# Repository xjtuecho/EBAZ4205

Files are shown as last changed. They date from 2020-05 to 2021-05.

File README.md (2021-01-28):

# EBAZ4205

This development board was the control card of Ebit E9+ BTC miner. In mainland China, it cost about 5 dollars (<35 CNY) on the secondhand market.

## Resources

- [Telegram group](https://t.me/ebaz4205) general chat, quick Q&A
- [Wiki](https://github.com/xjtuecho/EBAZ4205/wiki) FAQ, tutorials
- [Github discussions](https://github.com/xjtuecho/EBAZ4205/discussions) troubleshooting help, projects, development

## Hardware summary

Hardware:
- [PDF Schematic](/HW/ebaz4205/EBAZ4205-SCH.pdf)
- [Altium Designer design files](/HW/ebaz4205/altium/)
- [KiCad design files](/HW/ebaz4205/kicad/)
- [CPU info](proc/cpuinfo)

On-board linux
- [Kernel cmdline](proc/cmdline)
- [NAND Memory Map](proc/mtd)
- [Linux Version](proc/version)

The TF card socket is absent by default, you can buy and solder it by yourself if necessary. So do the UART port `J7`and the JTAG port `J8`.
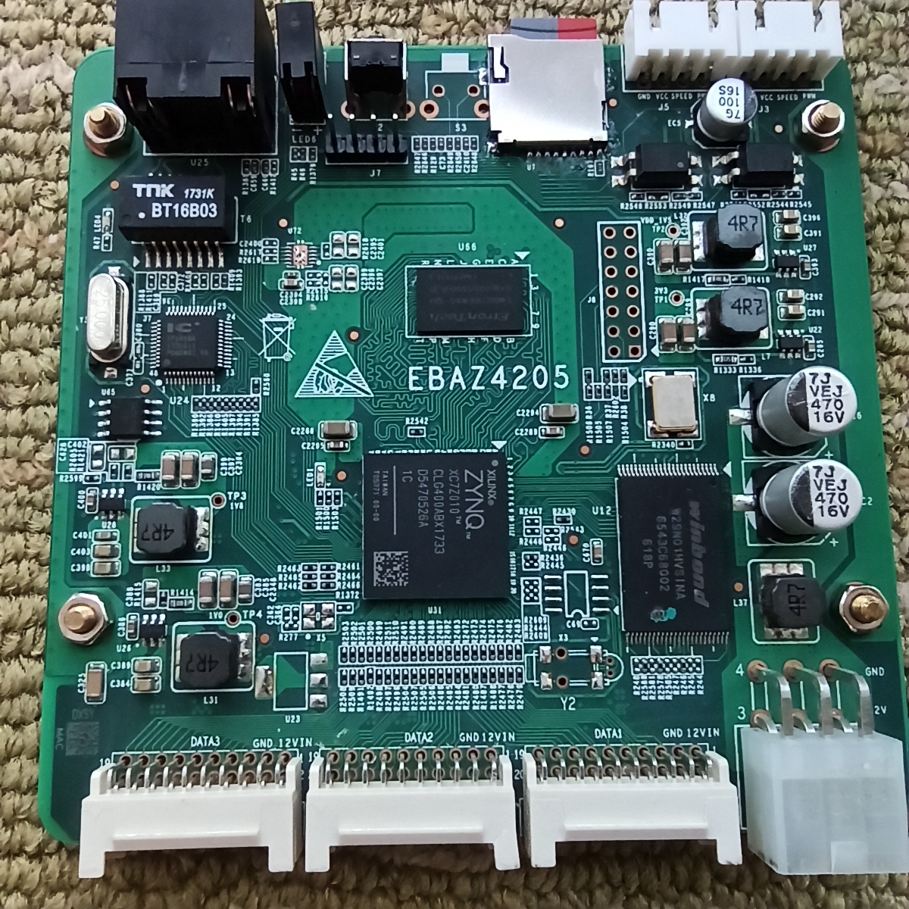
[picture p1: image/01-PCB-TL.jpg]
Top layer of the board


On the bottom layer of the board, diode `D24` is absent by default, which you need if you want to power the board via `J3 J4 J5`. Solder a SMC schottky diode there.
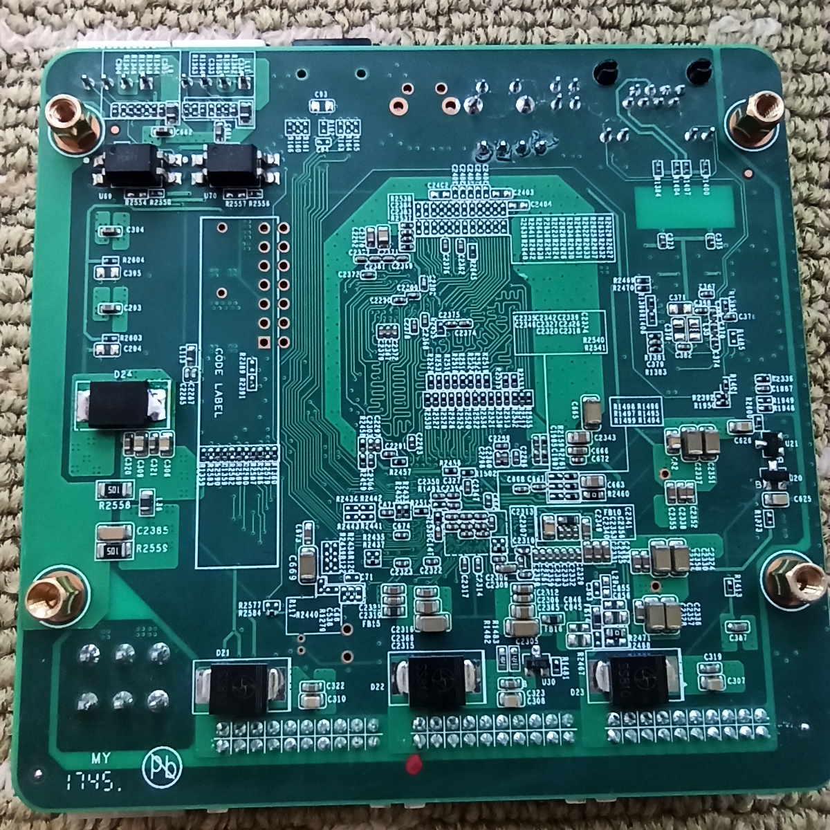
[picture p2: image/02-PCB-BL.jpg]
Bottom layer of the board


XC7Z010CLG400, Dual Core Cortex A9 @ 666.66MHz and Artix-7 FPGA with 28k LEs.
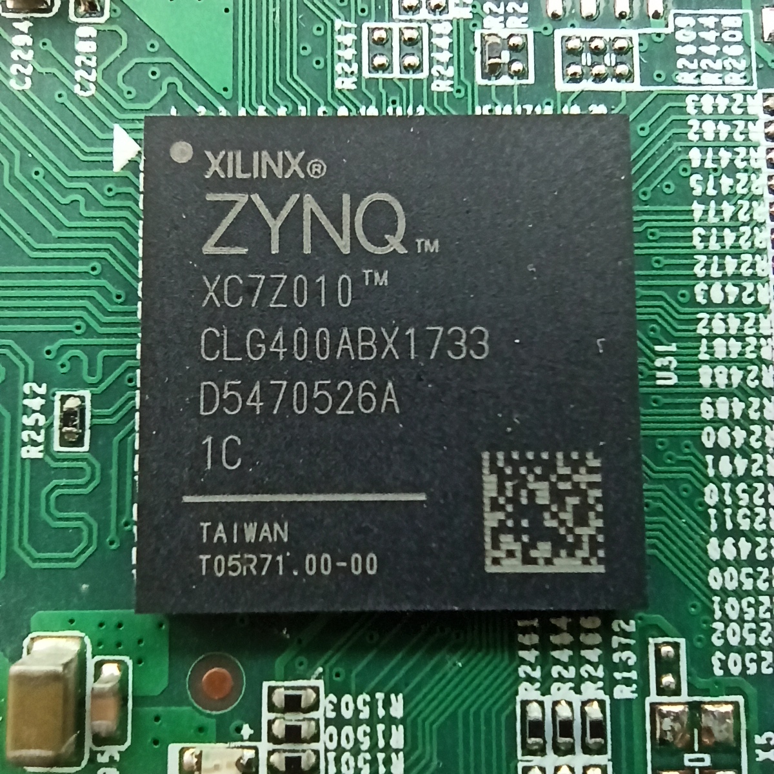
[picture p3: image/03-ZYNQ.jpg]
ZYNQ


256MB DDR3 Dynamic Memory.
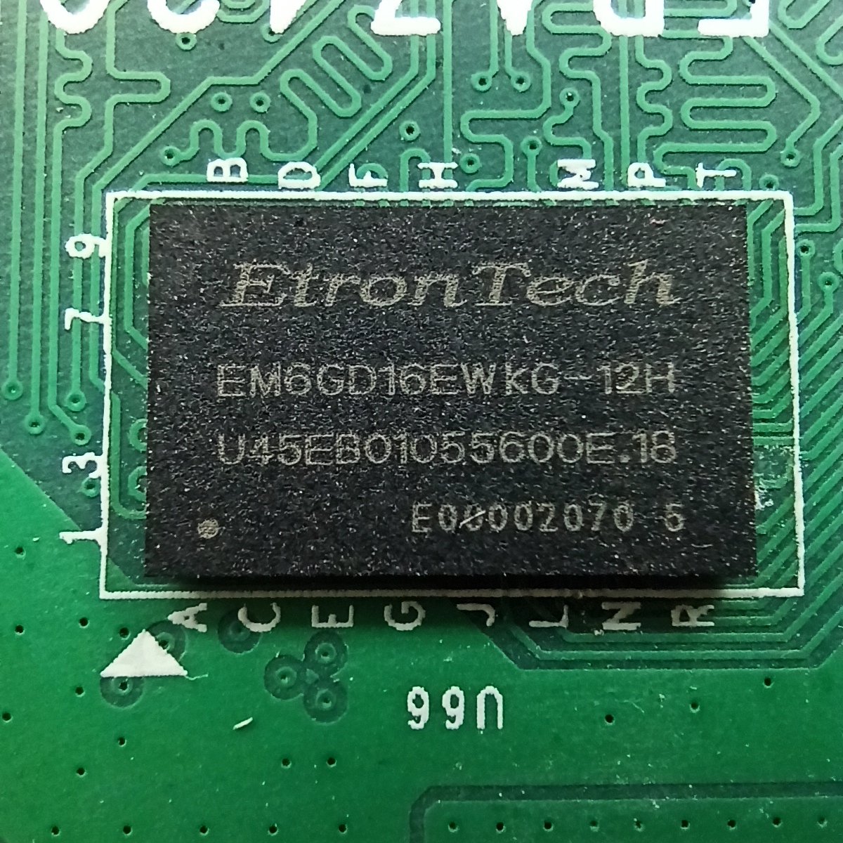
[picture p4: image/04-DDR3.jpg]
DDR3


128MB SLC NAND FLASH.
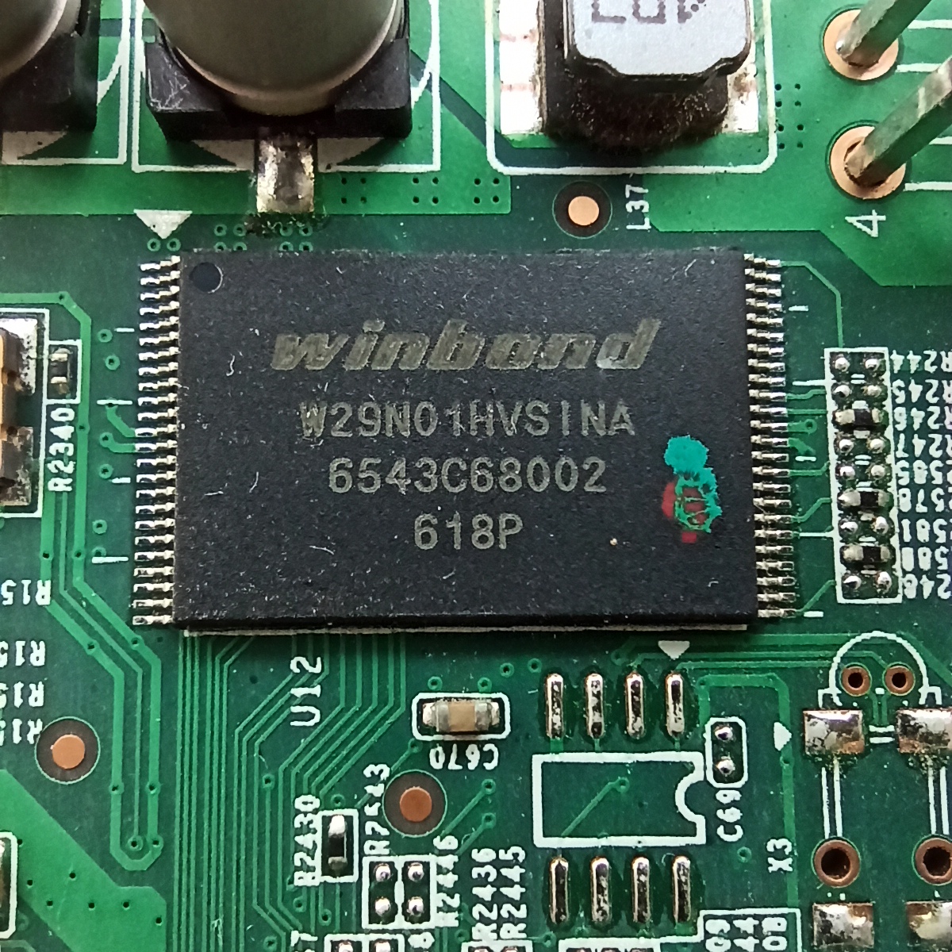
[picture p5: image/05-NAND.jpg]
NAND


10/100Mbps Ethernet transceiver: IP101GA
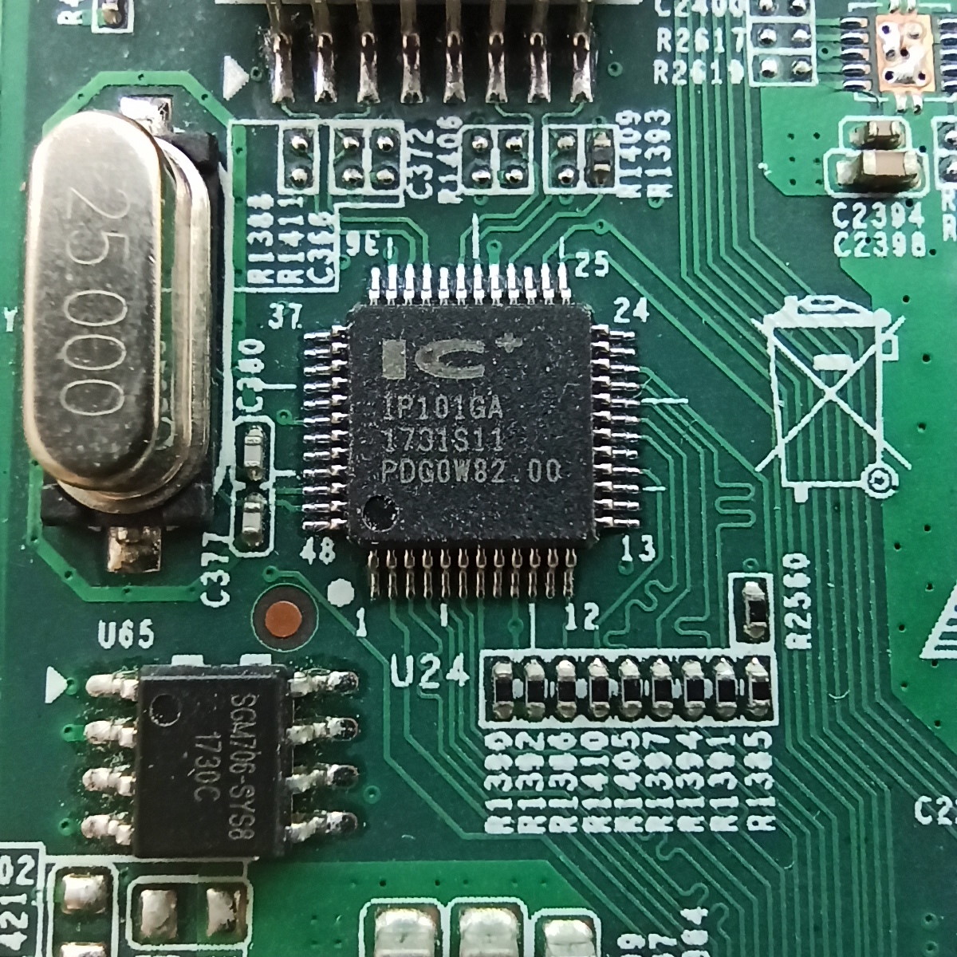
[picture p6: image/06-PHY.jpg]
PHY


BOOT Select Resistor: `R2577 and R2584`. The resistor is on `R2584` by default, which indicates boot from NAND. If you want to boot from TF card, **move** `R2584` to `R2577`.
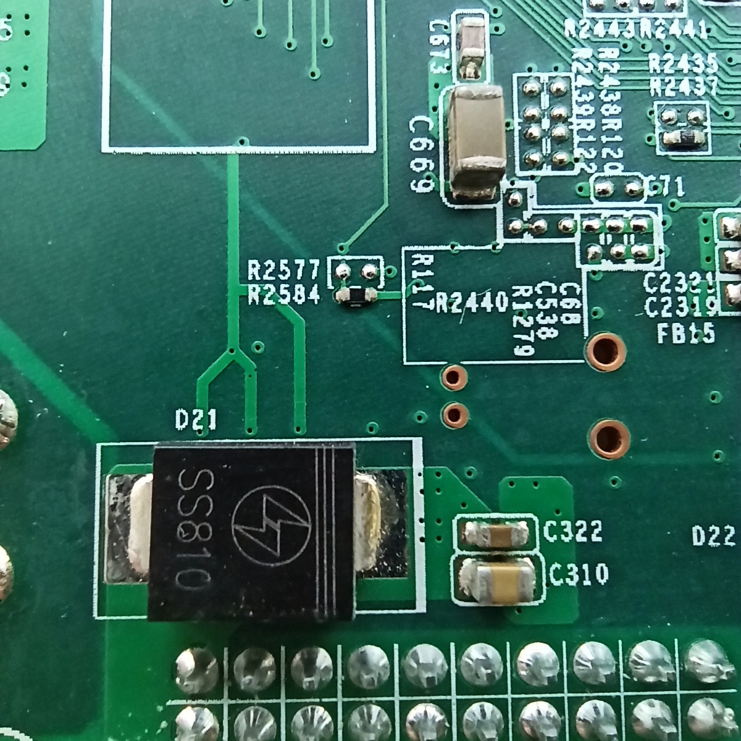
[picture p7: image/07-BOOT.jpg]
BOOT


## Powering the board

If the Schottky Diode `D24` was not mounted, you can only power the board by `DATA1` `DATA2` and `DATA3` port. Voltage 5V~12V is OK, 400mA and above is necessary. The pin distance of these three ports is 2.0mm, which is not common as 2.54mm.

After `D24` was mounted, we can power the board by J3 J4 J5. For convenience, J3 or J5 is recommended, which was originally for FAN power.

## Reset the root password of built-in linux

Use HyperTerminal or Putty to connect the TTL port, TXD RXD and GND is enough, VCC is not necessary. Power the Board, Hit `d` to enter the u-boot shell.

```
setenv nandboot "echo Copying Linux from NAND flash to RAM... && nand info && run nandroot;nand read 0x100000 0x2220000 0x300000 && fpga loadb 0 0x100000 0x300000 && nand read ${kernel_load_address} 0x300000 ${kernel_size} && nand read ${devicetree_load_address} 0x800000 ${devicetree_size}"
run nandboot
setenv bootargs 'console=ttyPS0,115200 root=/dev/mtdblock6 rootfstype=jffs2 noinitrd rw rootwait reboot=cold,hard emergency init=/bin/sh'
bootm ${kernel_load_address} - ${devicetree_load_address} init=/bin/sh
passwd
```

Use the commands above to reset the root password.

## Shut down the BTC miner program

After logging on with root, execute commands below to disable the BTC miner program.

```
mv /etc/rcS.d/S95cgminer.sh /etc/rcS.d/K95cgminer.sh
reboot
```

## Set static IP address

Edit configuration file: `/etc/network/interfaces`, add contents below.

```
auto eth0
iface eth0 inet static
address 192.168.1.205
netmask 255.255.255.0
gateway 192.168.1.1
dns-nameservers 192.168.1.1
```

Enable ethernet: `ifup eth0`.
Check ethernet status: `ethtool eth0`
Now you can use `ssh root@192.168.1.205` to connect the built-in linux.
Of course, you can use other IP address according to your network configuration.

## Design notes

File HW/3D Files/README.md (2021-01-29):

# EBAZ4205 3D Files

## EBAZ4205_Stand.stl

Uses four 5mm M3 Screws.
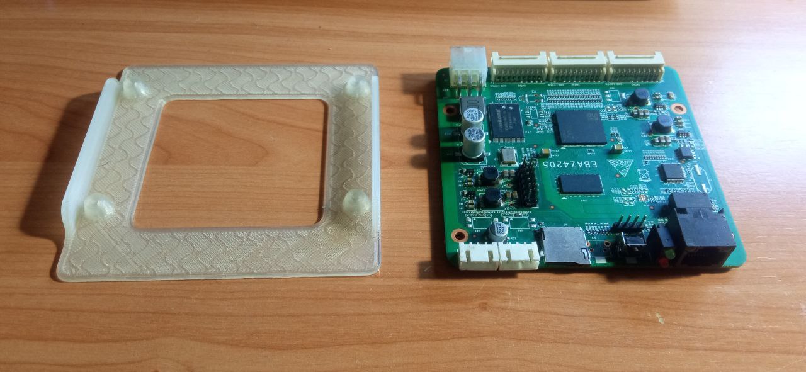
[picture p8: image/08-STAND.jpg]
Unmounted Stand

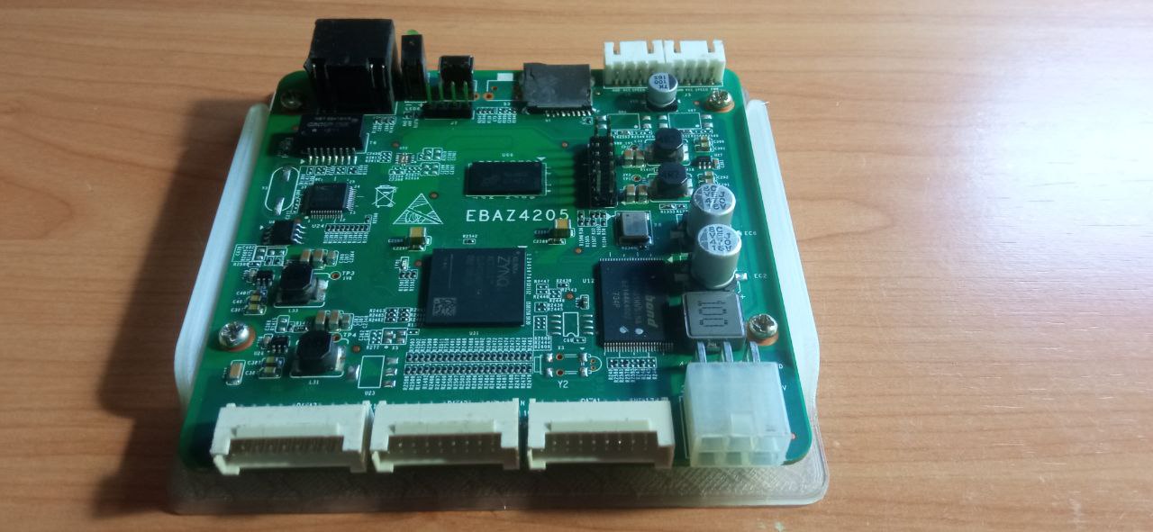
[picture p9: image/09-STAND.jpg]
Mounted Stand


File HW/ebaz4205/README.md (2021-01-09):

# EBAZ4205 PCB designs and schematics

[original](./original) contains the original design (PCB only).

## Altium & KiCad import tutorial

Tools required:
- Altium 20 (21 has importer issues)
- latest KiCad nightly - [Windows builds](https://kicad-downloads.s3.cern.ch/index.html?prefix=windows/nightly/)

1\. Download original PCB file from https://github.com/Elrori/EBAZ4205/blob/master/ebit.pcb

---

2\. Import it in Altium Designer 20 or lower (v21 has a broken importer) via the DXP import wizard

2.1 Use define board shape from bounding rectangle

2.2 Other options are greyed out and turned off

2.3 20mil Internal Plane Pullback (default)

---

3\. Fix import issues in Altium

3.1.1. In PCB List (View > Panels > PCB List) locate "Pads" objects that have "Stack mode property" set to "Top-Middle-Bottom"

3.1.2. In the Properties window, change it to "Simple", keep the Shape "Rectangular"
	   (It will cause DRC issues with polygon fills which we will fix)

3.2. Polygon pour priorities seem to be screwed up and that affects KiCad (since Kicad doesn't keep around filled polygons). \
     It's possible that this is actually an issue of the original design - they poured polygons in parts, never fully.
	 \
     So even though Altium keeps previous fills, we need to to fix that in Altium (has better tools for this) so that it works in KiCad.

3.2.1. Go to Tools > Polygon Pours > Polygon Manager

3.2.2. Select all polygons (Ctrl+A) in Properties set "Hatched" to "Solid", disable "Remove Islands", keep other settings as-is

3.2.3. For every layer, Auto Generate Pour Order

3.2.4. Apply and close Polygon Manager

3.3. Default design rules mangle poly fills

3.3.1. Go to Design > Rules

3.3.2. Set "PolyonConnect" rule "Connect Style" property to "Direct Connect" \
       (This removes thermals reliefs on specific pins, but at least you don't need to dick with DRC rules too much)
	   
3.3.3. Set "Clearance_1" minimum clearance 3.2mil to pass the DRC check \
       (Or, alternatively, fix these issues, there's only 4 or so violations)

3.4. Repour all polygons via Tools > Polygon Pours > Repour All

---

4\. Save the design as ebit_ad.PcbDoc , use "PCB Binary Files" type (this is version 6 of the format, which is expected by the Kicad importer).

---

5\. Import the design in KiCad nightly (I've used 5.99.0-8236-gc3d46c1cb5, Jan 7 2021 22:02:27, CERN Windows build) 

5.1. Open pcbnew directly

5.2. File > Import > Non-KiCad board file, select ebit_ad.PcbDoc (it needs to have the PcbDoc extension!)

5.3. Fix import issues in KiCad \
     Constraints aren't migrated properly (though the values in Altium don't make much sense either) \
	 so we need to manually set it to Altium rules to get comparable results
	 
5.3.1. Go to File > Board Setup

5.3.2. Board Stackup > Physical Stackup, set Board thickness to Current thickness from stackup \
       (or actually fix / adapt it to your manufacturers capabilities)

5.3.3. Design Rules > Constraints, set to Altium rules (or manufacturer capabilities)

  - Copper > Minimum track width to 1 mils
  - Copper > Minimum annular width to 3 mils
  - Copper > Minimum via diameter to 2 mils
  - Copper > Copper edge clearance to 3.2 mils
  - Holes > Minimum through hole to 2 mils
  - Holes > Hole to hole clearance to 10 mils
  - you can ignore other settings

5.3.4. Design Rules > Violation Severity

  - set Miscellaneous > Silkscreen overlap to Ignore
  - set Miscellaneous > Silkscreen clipped by solder mask to Ignore

5.3.5. Project > Net Classes, Default+All nets, set to Altium rules (or manufacturer capabilities)

  - Clearance to 3.2 mils
  - Track Width to 10 mils
  - Via Size to 50 mils
  - Via Drill to 28 mils
  - you can ignore other settings

5.3.6. Apply and close Board Setup

5.4. Set up zone fills

5.4.1. Open Copper Zone Properties (Ctrl+Shift+Z)

5.4.2. Set Electrical Properties

  - Clearance to 3.2 mils
  - Minimum width to 3.2 mils
  - Pad connections to Solid
  - you can ignore other settings

5.4.3. Invoke "Export Settings to Other Zones" and close the Copper Zone Properties

---

6\. Due to https://gitlab.com/kicad/code/kicad/-/issues/5794 (still applicable),
   invoke zone refill in DRC checker to apply new net clearances
   \
   If you set everything as described, the DRC checker shouldn't report any errors
   and all nets should be connected.

---

7\. Save the KiCad design if you haven't already ;)

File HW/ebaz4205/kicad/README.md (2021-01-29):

# Please note

At the time of writing (Jan, 2021) you require a nightly build of KiCad to be able to view this PCB / schematic.

Once KiCad v6 lands, you will be able to use stable versions.

Nightly version was required because the significantly improved Altium PCB importer (bundled within pcbnew, not a standalone tool)
isn't available in the stable builds yet.

KiCad schematic capture (eeschema) has also switched to a new file format (s-expr),
for which it was significantly easier to write a schematic generation tool (https://github.com/tpecar/nl2sch).

## Getting KiCad nightly

If you're on Windows, CERN provides pre-built binaries (see bottom of page for latest version)

https://kicad-downloads.s3.cern.ch/index.html?prefix=windows/nightly/

For Linux it depends on the distribution - for Ubuntu/Debian, the instructions are provided on the KiCad page

https://kicad.org/download/ubuntu/#_nightly_development_builds

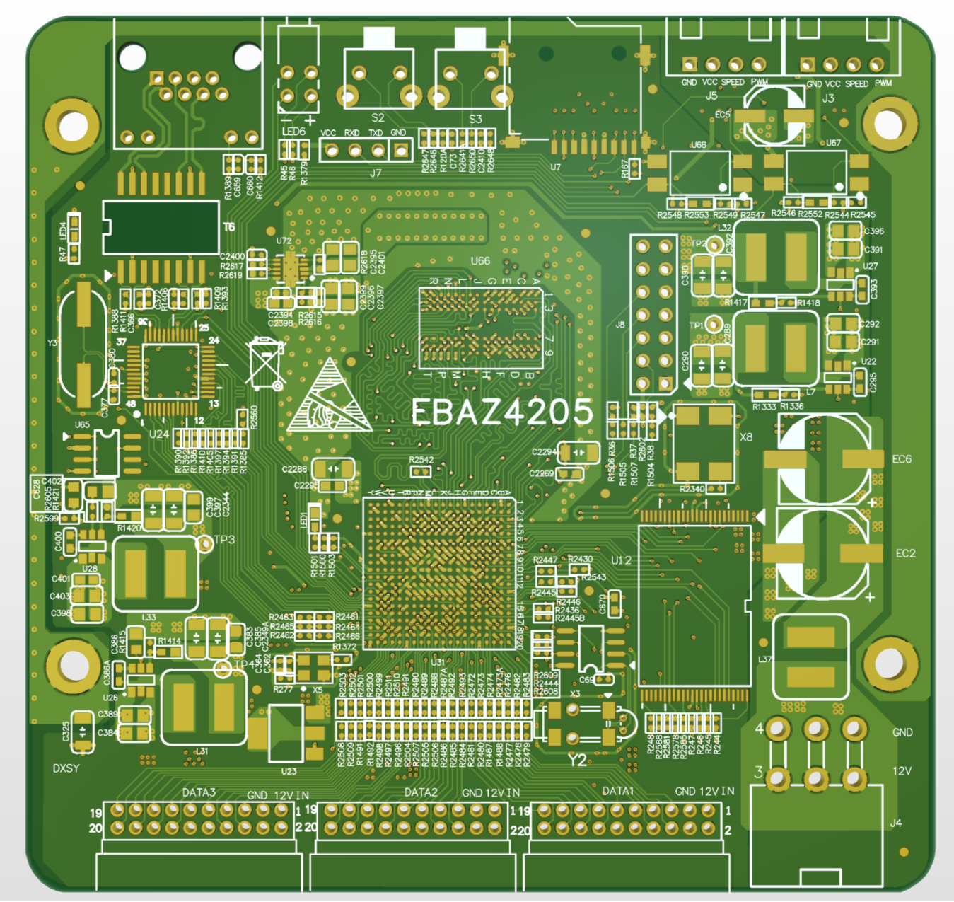
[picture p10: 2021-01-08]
HW/ebaz4205/EBAZ4205-3D.png

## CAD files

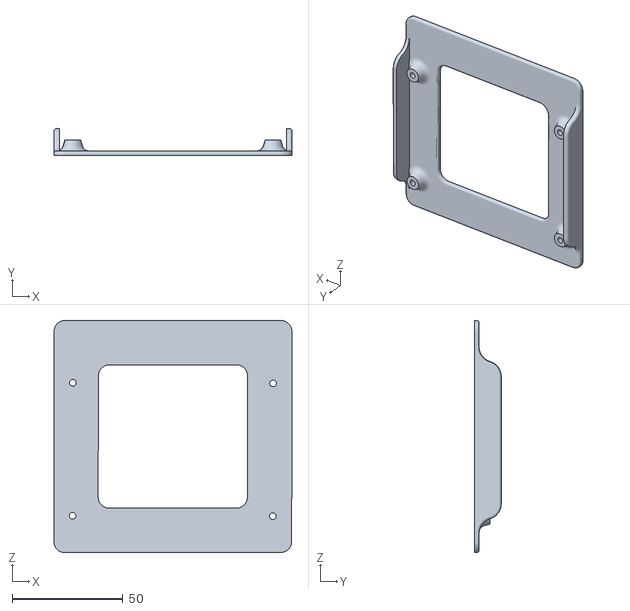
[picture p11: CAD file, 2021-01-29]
HW/3D Files/EBAZ4205_Stand.stl
107.2 x 12.0 x 104.6

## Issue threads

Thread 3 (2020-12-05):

KG4205 Development board VGA &UART

firepower9966, 2020-12-05:
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

Do you have any info on KG4205 Which match the EBAZ4205.  It provides VGA and UART and a 2.54mm  I/O connector which can attach optional camera.

xjtuecho, 2020-12-09:
This KG4205 is an extended card of EBAZ4205. I didn't know more about it, but  I can purchase it easily in my country.

ryanm101, 2020-12-20:
Seems you can buy a few adaptors: https://www.aliexpress.com/item/1005001530233006.html?spm=2114.12057483.0.0.61c9febeBUtvsg

Where can you buy the KG4205 from?

firepower9966, 2020-12-20:
US $17.69  9%OFF | ZYNQ7010 Development Board, Xc7z010 FPGA.
https://a.aliexpress.com/_msejyAv

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

artemglukhov, 2021-02-01:
May I ask you if you know the part number of these 2x10 20mm connectors?

firepower9966, 2021-02-01:
Search for
20 Position 2 mm 2 Row Headers & Wire Housings
Depends if you want wired connector or PCB mount.

BrainHunter, 2021-03-20:
does anyone have schematics for this board?

nic3-14159, 2021-03-20:
> does anyone have schematics for this board?

There's some info about this board in the discussions
https://github.com/xjtuecho/EBAZ4205/discussions/46

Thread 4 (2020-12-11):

Information on readme how to upload bitstream to FPGA?

Kazhuu, 2020-12-11:
Hello! I'm relative new to Xilinx FPGAs and ordered one of these boards. I'm wondering what is the best way to actually do some FPGA development on this board? I think I can put the bitstream file to SD card and let linux upload it to FPGA on boot but cannot find any information about this. Also someone on Reddit mentioned that you need JTAG FPGA programming cable from Xilinx. I guess this would be the best way to do the development? But the cable itself cost something like 80€ I think.

I've used Altera's development boards earlier which can be used with USB cable instead. Thank you!

xjtuecho, 2020-12-11:
Maybe you need a Digilent JTAG-SMT2，the FT232HL_v20.5.31.pdf in this repo is enough. cost about 8$

Kazhuu, 2020-12-11:
Thanks! With this information I was actually able to do some research and found web page describing [programming solutions](https://store.digilentinc.com/jtag-programmers-fpga-programming-solutions/). I'll also had a look at FT232HL board you mentioned and was thinking could [this](https://www.adafruit.com/product/2264) Adafruit one serve similar purpose? Of course with this you have to connect the pins individually.

tpecar, 2020-12-12:
Hi, [I'm probably from the same bandwagon as @Kazhuu](https://hackaday.com/2020/12/10/a-xilinx-zynq-linux-fpga-board-for-under-20-the-windfall-of-decommissioned-crypto-mining/).

With a bunch of these on the way I'm also in the process of figuring out how to use them :rofl:

The cheapest way to get going is probably to just build the SD card image and boot the board from that. Most examples available for this board go this way
- https://www.jianshu.com/p/b83c663ecaaa
- https://gitee.com/actionchen/ebaz4205_hw/blob/master/Doc/ebaz4205_introduce.md
- https://www.youtube.com/watch?v=b6g5tNZZnVc

However, in order to debug a baremetal application running on PS (ARM core) and to not loose sanity swapping SD cards, I also want to figure out how to use JTAG.

#### The easy and expensive way of doing this
The [Digitlent JTAG cables](https://store.digilentinc.com/jtag-programmers-fpga-programming-solutions/) are the official cables that are supported by Xilinx tools. If you want the minimum amount of fuss, get one of these.

However, given that they are only glorified FTDI dongles programmed with configuration blessed by Xilinx, it makes me a bit mad spending $60 for one of these.

#### The cheap and finnicky way of doing this
While I couldn't find a product that uses the exact design specified in FT232HL_v20.5.31.pdf, I suppose that most generic FTDI JTAG dongles are applicable here.

You can then use [OpenOCD](http://openocd.org/) or [xc3sprog](http://xc3sprog.sourceforge.net/) to download the bitstream to the fpga (provided that you have boot mode pins set to JTAG - these are the same pins @xjtuecho suggests to change to get SDcard boot).

There's a couple of gotchas however:
- xc3sprog is only capable of setting up the PL (FPGA) side, PS (ARM core) is uninitialized
- OpenOCD has support to set up PL / PS sections
  - [OpenOCD page](https://devel.rtems.org/wiki/Debugging/OpenOCD/Xilinx_Zynq) has configuration files for Zynq but it needs to be adapted to your specific chip
  - [Zynq-RS project](https://git.m-labs.hk/M-Labs/zynq-rs) has configuration files set up for Z7-10

  but is not supported by Xilinx, so there's probably some effort required to get a decent debugging environment
- none of these metods give you access to [ILA](https://www.xilinx.com/video/hardware/logic-debug-in-vivado.html)

Then you have _Xilinx Virtual Cable (XVC)_.
Seems to be the most interesting method. Instead of talking to the debug probe directly, the Xilinx tools talk to a XVC deamon over TCP/IP, which can run on your system or some other device, which is actually connected to your target
- [original XVC deamon](https://debugmo.de/2012/02/xvcd-the-xilinx-virtual-cable-daemon/) and [its sister project](https://code.google.com/archive/p/playtag/) run on your development system and talk to the target via FTDI2232 (essentially bypassing the silly restrictions). However, these projects seem to be inactive.
- [Xilinx has reworked this code to run directly on a Zynq platform](https://github.com/Xilinx/XilinxVirtualCable), so if you have more than one board, you can use one as a debug probe.
- [somebody has ported the Xilinx example on the Raspberry Pi](https://github.com/derekmulcahy/xvcpi) so you can try that.

Kazhuu, 2020-12-12:
@tpecar thanks for the very detailed answer! This really helps people like me to get started and learning. Very appreciated! I think I might end up buying a cable from Digilent because it can also be used in the future with different boards. And I'm interested in the debugging support which is quite mandatory when doing anything more complicated.

One thing I'm wondering. If I buy JTAG-HS3 instead of JTAG-HS2. HS3 has support for PS_SRST pin resetting the processor during debugging. Although I checked the schematics of this board and it seems this pin is not connected to JTAG header. I'm guessing if you want PS_SRST pin support then you'd need to modify the board.  Here is good explanation of [PS_SRST](https://forum.digilentinc.com/topic/580-jtag-hs3-vs-jtag-hs2-when-using-zynq-with-vivado/).

tpecar, 2020-12-12:
Well, given that they sell both JTAG-HS2 and JTAG-HS3 for the same price, I guess you select the one that better fits your use case.

HS2 supports [2-Wire JTAG](https://sudonull.com/post/106128-We-disassemble-the-2-wire-JTAG-protocol), but since we already have standard JTAG routed out, this is a non-issue.

HS3, as you mentioned, has an open drain output which the Xilinx tools can use for PS reset.

The PS_SRST_B (B10 on CLG400 package) is routed out to R2430 (pullup to VCC) which is perfect - just run a bodge wire to the JTAG connector (pin 12, 14 of the connector seem to be disconnected).

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

Kazhuu, 2020-12-13:
Thanks you for you detailed answer! I'll order one and try it out. Sorry might be beginner question but what I understood that HS3 has open drain outputs, meaning that I have to connect it to VCC pull up like you said. So in this case I need to connect from the **left side** of the resistor to pin 14 like so.

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

tpecar, 2020-12-13:
Yep, that should work.

It obviously needs to be tested, and I probably have a good 2 months before I get the boards, so if you can try that earlier I'll appreciate your report.

Once it gets tested, we can consider integrating it into the readme.

Kazhuu, 2020-12-13:
Sounds good. I can test it but it might not be very soon because I'm not at home during Christmas holidays and getting that cable to Finland will take some time delivered. I'll report here when I've tested this.

tpecar, 2020-12-13:
> getting that cable to Finland will take some time delivered

Just in case you didn't notice, Digilent has European distributors - you can get the cable at [Farnell for example](https://analytics.oemsecrets.com/main.php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).

ustcpetergu, 2020-12-16:
Actually, you can download the bitstream over ethernet in u-boot. So no need to solder SD card slot or buy expensive JTAG downloaders. UART is still needed though.

Set up a tftp server on host computer and in u-boot use command similar to this:
```
<press d>
setenv serverip 192.168.6.6
setenv ipaddr 192.168.6.136
tftpboot 0x100000 bd_hello_wrapper.bit.bin
fpga load 0 0x100000 0x1fcba0

reset
```
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
xjtuecho, 2021-01-28:
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
What's the version of you KiCad? I can't open the KiCad project with latest KiCad 5.1.9-1

tpecar, 2021-01-28:
I'm using nightly build of kicad (compiled from current git master), it's numbered as version 5.99.

I've needed to use nightly because the have significantly improved the Altium PCB importer and they have switched to s-expr file format for eeschema, for which it was easier to write a schematic generation tool.

If you're on Windows, CERN provides prebuilt binaries (see bottom of page for latest version)
https://kicad-downloads.s3.cern.ch/index.html?prefix=windows/nightly/

For linux it depends on the distribution - for Ubuntu/Debian, the instructions are provided on the Kicad page
https://kicad.org/download/ubuntu/#_nightly_development_builds

M3m3M4n, 2021-09-27:
> And about JTAG downloader, I did by one later. But of course not the expensive official one. I just picked a CJMCU FT232HL(the one with purple PCB, which is quite common) module and flashed the EEPROM. Similar to this: https://gist.github.com/rikka0w0/24b58b54473227502fa0334bbe75c3c1
>
> The firmware between FT232 and FT2232 may be a little different so the gist may not work out-of-the-box, but I got it working at last. Only cost me 30RMB.

@regymm Does the firmware need to be modified? can you share the binary?

regymm, 2021-09-27:
For FT2232 just follow the link. You can try this one(use xxd to reverse to binary) for FT232, and change the product_id and file name in the link-provided configuration file accordingly. Run `dmesg --follow` and re-plug your downloader to see whether the firmware is successfully flashed. May need multiple tries but this is not that hard.
```
00000000: 0100 0304 1460 0009 8000 0800 0000 a012  .....`..........
00000010: b228 da1a 0000 0000 0000 0000 0000 5600  .(............V.
00000020: 0100 c792 6a35 5401 0031 4a74 6167 536d  ....j5T..1JtagSm
00000030: 7432 0000 0000 0000 0000 0044 6967 696c  t2.........Digil
00000040: 656e 7420 4a54 4147 2d53 4d54 3200 0000  ent JTAG-SMT2...
00000050: 0000 0000 0000 0000 1300 0000 0000 0000  ................
00000060: 0000 0000 0000 0000 0000 0000 0000 0000  ................
00000070: 0000 0000 0000 0000 0000 0000 0000 0000  ................
00000080: 0000 0000 0000 0000 0000 4800 0000 0000  ..........H.....
00000090: 0000 0000 0000 0000 0000 0000 0000 0000  ................
000000a0: 1203 4400 6900 6700 6900 6c00 6500 6e00  ..D.i.g.i.l.e.n.
000000b0: 7400 2803 4400 6900 6700 6900 6c00 6500  t.(.D.i.g.i.l.e.
000000c0: 6e00 7400 2000 5500 5300 4200 2000 4400  n.t. .U.S.B. .D.
000000d0: 6500 7600 6900 6300 6500 1a03 3200 3100  e.v.i.c.e...2.1.
000000e0: 3000 3200 3500 3100 4100 3000 3800 3800  0.2.5.1.A.0.8.8.
000000f0: 3700 3000 0203 0000 0000 0000 0000 9887  7.0.............
```

M3m3M4n, 2021-09-27:
Thanks.
Also earlier I missed a comment on https://gist.github.com/rikka0w0/24b58b54473227502fa0334bbe75c3c1 that mentions the HS2 firmware is confirmed working with 232h.

AndersBNielsen, 2021-12-10:
I have a FT232 coming in the mail but to anyone that has a Raspberry Pi around: xvcpi was suuuuper easy to use.
Simply connect it to the "SPI" port on the RPi + GPIO25 and you can connect through Vivado. Super handy with a Pi Zero W - Wireless JTAG :)

regymm, 2021-12-10:
Yeah, RPi's neat. How long does it take to program ZYNQ 7010? I'd like to use RPi but seems on my side it takes more than half a minute and when using ILA to capture data it's very slow.

nic3-14159, 2021-12-12:
@regymm  The xvcpi code, built without changes, programs my board in about 20s. Lowering the clock delay as much as I could, I was able to get it down to about 8s. However, there seems to be a timing issue with the code which limits the minimum clock delay/maximum clock rate, after fixing that (I have a pull request open in the original repo) I was able to get the programming speed down to 3s after setting the clock delay to 0.

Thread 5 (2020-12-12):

SchDoc for EBAZ4205.PcbDoc

tpecar, 2020-12-12:
Do you have access to the PcbSch (schematic file) of the design?

We can obviously make do with the pdf export, but the actual design file would be welcome so that we can utilize cross-probing in Altium.

tpecar, 2020-12-12:
Also, correct me if I'm wrong, but it seems that some traces / planes are missing in the PCB design?

Notably, some VCC lines (I've looked at R2430) don't seem to go anywhere.

xjtuecho, 2020-12-13:
sorry, no .schdoc. The pdf schematic and PcbDoc are probably not the original design. Maybe they are the product of some reverse engeering.

tpecar, 2020-12-13:
Ok, thank you. The design files probably originate from the initial design, but it seems that someone has removed a couple of nets while this design was passed around.

It seems that the original reseller of this board on AliExpress was aware of such versions, noting "PCB (ad format copy board diagram, you can only refer to it, it is not recommended to proof)".

In the meantime I've found a more complete PcbDoc at
https://github.com/Elrori/EBAZ4205

I'll contact him to see if he has any more info.

tpecar, 2020-12-19:
Well, I'm currently still waiting for an answer from Elrori, but I did some digging of my own in the meantime.

This board was making rounds on chinese EE forums in the early/mid 2019, and the relevant development resources have been reposted many times over. We're probably well past the point where anyone affected would care about further distributing these files, so the least we can do is organize them.

@xjtuecho I suggest that you have a look at Elrori's version of the pcbdoc and replace your version with his.

tpecar, 2020-12-19:
Here's a couple forum threads from when the boards initially hit the chinese flea market.
I didn't yet bother to register on them, so I didn't check the files.

- http://bbs.eeworld.com.cn/thread-1078942-1-1.html
- http://bbs.eeworld.com.cn/thread-1079275-1-1.html
- https://whycan.com/t_2297.html
- https://www.amobbs.com/thread-5708955-1-1.html#postmessage_10672027

Also http://dengkanwen.com/ seems to run http://www.opensoc.cn/ which sells expansion boards that were mentioned in some other issue, but most of their documentation seems broken.

tpecar, 2021-01-05:
After looking around various forums and looking through the materials that people have gathered on the Telegram group, we can assume that the original schematic file was never shared.

So if we want cross probing, we'll have to recreate it.

I will close this issue when I transfer the useful information to the Wiki.

Closed 2021-01-05.

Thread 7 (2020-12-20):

Frequency info

doppioandante, 2020-12-20:
If I can correctly interpret the pics, the external crystal is at 25MHz, is this correct? Does the FPGA run at this frequency?

tpecar, 2020-12-20:
The 25MHz crystal (Y3) is for the ethernet phy.

Zynq uses the 33.333MHz crystal (X8), which can then be internally multiplied by a PLL - this depends on your design, the firmware already present on the flash chip seems to use 666.66 MHz for the ARM core (judging from the BogoMIPS).

The overview datasheet specifies max frequency 667MHz for grade 1 Z-7010  used on these boards. But again, the actual frequency you can use will be determined by your design.

doppioandante, 2020-12-20:
Thank you, that's exactly what I needed to know

Closed 2020-12-20.

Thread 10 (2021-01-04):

Add categories to Github discussions

tpecar, 2021-01-04:
Add additional categories which would be useful to the project

- Troubleshooting - for helping people setting up their board
- Documentation - for discussion about tutorials, learning materials, Wiki
- Development - for research on the development board, promotion of useful tools and projects

I would use the "Open ended discussion" format for these.

Existing categories are very general, but I would keep them for whatever discussion that doesn't fit in the suggested categories.

tpecar, 2021-01-05:
Thank you for creating the categories.

Closed 2021-01-05.

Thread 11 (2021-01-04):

Get schematics etc from behind the great wechat paywall

ryanm101, 2021-01-04:
This issue is to track a list of files we want to gather that have been uploaded to various sites that require wechat accounts to download from.

Closed 2021-01-04.

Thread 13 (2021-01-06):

Missing Components

firepower9966, 2021-01-06:
I just received my EBAZ4205 from aliexpress, I noticed some components are missing compared to PCB in Photo
Missing: (next to J5, J3)
U67, R2546, R2544, R2545
U68, R2548, R2549, R2547
U69, R2554, R2551
U70, R2557, R2555
Added:
R2553, R2552, R2554, R2557

Missing: (Lan)
Y3 25MHz xtal
C377, C380 22pF

tpecar, 2021-01-06:
There are at least two known hardware revisions of the board:
1. version, pictured in the repo README, which has the phy + optocouplers
2. version (**what you have**), where these components (+various resistors and caps) are missing

They presumably use the same PCB. It has been speculated that they have different software / bitstream configurations and that in the 2nd version the FPGA generates the clock for the phy.

However, I haven't looked into this myself, other members may have more information on this.

Kudos for identifying the missing components and measuring their values - I suggest that you add them to [hardware build states wiki page](https://github.com/xjtuecho/EBAZ4205/wiki/Hardware-Build-States.-What-you-may-or-not-have-fitted-on-your-board.).

tpecar, 2021-01-06:
Also, it's probably a good idea that people start nagging their sellers to partially refund them for falsely advertising their product and to force them to update the product image.

Most, if not all, sellers use the 1. version for the product image (which was probably made early in the devices product cycle) but sell you the 2nd. There have been numerous reports about this already.

firepower9966, 2021-01-06:
my seller sold both types, i selected the cheaper version which had no sdcard and jumpers, but they were supplied to be soldered by user. did not realized other components were missing though, pictures of both boards were shown.

nic3-14159, 2021-01-06:
Mine was missing the opto-isolators and 25MHz crystal as well, where the opto-isolators were bypassed by those extra 33 ohm resistors. I took a look at the schematic and my board and found that the 10k ohm resistors R1344 and R1361 are pull-ups to 3.3V on pin 3 (labeled as SPEED on the board) of both J3 and J5. So using logic levels of less than 3.3V on those pins should probably be avoided if using a board with the missing components. Alternatively, just remove those resistors.

Looking at the schematic again, it seems like if the opto-isolators are present, R2350 (the board seems to say R2550, but the schematic says R2350) and R2556 pull up pin 4 on J3/J5 to VCC8, which is whatever voltage is on J4 or pin 2 on J3/J5. Those resistors are missing on the 2nd version of the board. With the opto-isolator, pin 4 (labled as PWM on the board) can only be used as an output, and the pull-up resistors means that the logical high voltage will be whatever VCC8 is. So if you have added the D24 diode to use J3/4/5 as the main power source, make sure that whatever is connected to pin 4 pin J3/5 can handle that voltage if using a board with the isolators.

I'll add this info to the wiki.

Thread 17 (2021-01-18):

Error running bootm command

dave18, 2021-01-18:
Hi

When trying to reset the password I get the following error when running the bootm command 'waiting for root device /dev/mtdblock6', the full Putty log is

------------------------------------------------------------
`
U-Boot 2015.07 (May 18 2017 - 22:22:09 +0800)

Model: Zynq Zed Development Board
DRAM:  ECC disabled 256 MiB
NAND:  128 MiB
MMC:   zynq_sdhci: 0
Invalid bus 0 (err=-1)
*** Warning - spi_flash_probe() failed, using default environment

In:    serial
Out:   serial
Err:   serial
Model: Zynq Zed Development Board
Net:   Gem.e000b000
Hit 'd' to stop autoboot(eric): 0
zynq-uboot> setenv nandboot "echo Copying Linux from NAND flash to RAM... && nand info && run nandroot;nand read 0x100000 0x2220000 0x300000 && fpga loadb 0 0x100000 0x300000 && nand read ${kernel_load_address} 0x300000 ${kernel_size} && nand read ${devicetree_load_address} 0x800000 ${devicetree_size}"
zynq-uboot> run nandboot
Copying Linux from NAND flash to RAM...

Device 0: nand0, sector size 128 KiB
  Page size       2048 b
  OOB size          64 b
  Erase size    131072 b
  subpagesize      512 b
  options     0x       0
  bbt options 0x   20000
## Error: "nandroot" not defined

NAND read: device 0 offset 0x2220000, size 0x300000
 3145728 bytes read: OK
  design filename = "top_ctrl;UserID=0XFFFFFFFF;Version=2016.4"
  part number = "7z010clg400"
  date = "2017/05/29"
  time = "11:17:01"
  bytes in bitstream = 2083740
zynq_align_dma_buffer: Align buffer at 100068 to 100000(swap 1)

NAND read: device 0 offset 0x300000, size 0x500000
 5242880 bytes read: OK

NAND read: device 0 offset 0x800000, size 0x20000
 131072 bytes read: OK
zynq-uboot> setenv bootargs 'console=ttyPS0,115200 root=/dev/mtdblock6 rootfstype=jffs2 noinitrd rw rootwait reboot=cold,hard emergency init=/bin/sh'
zynq-uboot> bootm ${kernel_load_address} - ${devicetree_load_address} init=/bin/sh
## Booting kernel from Legacy Image at 02080000 ...
   Image Name:   Linux-4.6.0-xilinx
   Image Type:   ARM Linux Kernel Image (uncompressed)
   Data Size:    3820688 Bytes = 3.6 MiB
   Load Address: 00008000
   Entry Point:  00008000
   Verifying Checksum ... OK
## Flattened Device Tree blob at 02000000
   Booting using the fdt blob at 0x2000000
   Loading Kernel Image ... OK
   Loading Device Tree to 0f2fe000, end 0f303a6b ... OK

Starting kernel ...

Booting Linux on physical CPU 0x0
Linux version 4.6.0-xilinx (root@alvin) (gcc version 5.2.0 (GCC) ) #5 SMP PREEMPT Mon May 8 14:36:49 CST 2017
CPU: ARMv7 Processor [413fc090] revision 0 (ARMv7), cr=18c5387d
CPU: PIPT / VIPT nonaliasing data cache, VIPT aliasing instruction cache
Machine model: xlnx,zynq-7000
cma: Reserved 16 MiB at 0x0e000000
Memory policy: Data cache writealloc
percpu: Embedded 12 pages/cpu @cfdcf000 s19776 r8192 d21184 u49152
Built 1 zonelists in Zone order, mobility grouping on.  Total pages: 65024
Kernel command line: console=ttyPS0,115200 root=/dev/mtdblock6 rootfstype=jffs2 noinitrd rw rootwait reboot=cold,hard emergency init=/bin/sh
PID hash table entries: 1024 (order: 0, 4096 bytes)
Dentry cache hash table entries: 32768 (order: 5, 131072 bytes)
Inode-cache hash table entries: 16384 (order: 4, 65536 bytes)
Memory: 234624K/262144K available (5286K kernel code, 231K rwdata, 1848K rodata, 1024K init, 226K bss, 11136K reserved, 16384K cma-reserved, 0K highmem)
Virtual kernel memory layout:
    vector  : 0xffff0000 - 0xffff1000   (   4 kB)
    fixmap  : 0xffc00000 - 0xfff00000   (3072 kB)
    vmalloc : 0xd0800000 - 0xff800000   ( 752 MB)
    lowmem  : 0xc0000000 - 0xd0000000   ( 256 MB)
    pkmap   : 0xbfe00000 - 0xc0000000   (   2 MB)
    modules : 0xbf000000 - 0xbfe00000   (  14 MB)
      .text : 0xc0008000 - 0xc07f7850   (8127 kB)
      .init : 0xc0800000 - 0xc0900000   (1024 kB)
      .data : 0xc0900000 - 0xc0939e60   ( 232 kB)
       .bss : 0xc0939e60 - 0xc0972764   ( 227 kB)
Preemptible hierarchical RCU implementation.
        Build-time adjustment of leaf fanout to 32.
        RCU restricting CPUs from NR_CPUS=4 to nr_cpu_ids=2.
RCU: Adjusting geometry for rcu_fanout_leaf=32, nr_cpu_ids=2
NR_IRQS:16 nr_irqs:16 16
efuse mapped to d0800000
slcr mapped to d0802000
L2C: platform modifies aux control register: 0x72360000 -> 0x72760000
L2C: DT/platform modifies aux control register: 0x72360000 -> 0x72760000
L2C-310 erratum 769419 enabled
L2C-310 enabling early BRESP for Cortex-A9
L2C-310 full line of zeros enabled for Cortex-A9
L2C-310 ID prefetch enabled, offset 1 lines
L2C-310 dynamic clock gating enabled, standby mode enabled
L2C-310 cache controller enabled, 8 ways, 512 kB
L2C-310: CACHE_ID 0x410000c8, AUX_CTRL 0x76760001
zynq_clock_init: clkc starts at d0802100
Zynq clock init
sched_clock: 64 bits at 333MHz, resolution 3ns, wraps every 4398046511103ns
clocksource: arm_global_timer: mask: 0xffffffffffffffff max_cycles: 0x4ce076117e, max_idle_ns: 440795215954 ns
Switching to timer-based delay loop, resolution 3ns
clocksource: ttc_clocksource: mask: 0xffff max_cycles: 0xffff, max_idle_ns: 537538477 ns
timer #0 at d080a000, irq=17
Console: colour dummy device 80x30
Calibrating delay loop (skipped), value calculated using timer frequency.. 666.66 BogoMIPS (lpj=3333330)
pid_max: default: 32768 minimum: 301
Mount-cache hash table entries: 1024 (order: 0, 4096 bytes)
Mountpoint-cache hash table entries: 1024 (order: 0, 4096 bytes)
CPU: Testing write buffer coherency: ok
CPU0: thread -1, cpu 0, socket 0, mpidr 80000000
Setting up static identity map for 0x100000 - 0x100058
CPU1: thread -1, cpu 1, socket 0, mpidr 80000001
Brought up 2 CPUs
SMP: Total of 2 processors activated (1333.33 BogoMIPS).
CPU: All CPU(s) started in SVC mode.
devtmpfs: initialized
VFP support v0.3: implementor 41 architecture 3 part 30 variant 9 rev 4
clocksource: jiffies: mask: 0xffffffff max_cycles: 0xffffffff, max_idle_ns: 19112604462750000 ns
pinctrl core: initialized pinctrl subsystem
NET: Registered protocol family 16
DMA: preallocated 256 KiB pool for atomic coherent allocations
cpuidle: using governor menu
hw-breakpoint: found 5 (+1 reserved) breakpoint and 1 watchpoint registers.
hw-breakpoint: maximum watchpoint size is 4 bytes.
zynq-ocm f800c000.ocmc: ZYNQ OCM pool: 256 KiB @ 0xd0880000
zynq-pinctrl 700.pinctrl: zynq pinctrl initialized
vgaarb: loaded
SCSI subsystem initialized
usbcore: registered new interface driver usbfs
usbcore: registered new interface driver hub
usbcore: registered new device driver usb
media: Linux media interface: v0.10
Linux video capture interface: v2.00
pps_core: LinuxPPS API ver. 1 registered
pps_core: Software ver. 5.3.6 - Copyright 2005-2007 Rodolfo Giometti <giometti@linux.it>
PTP clock support registered
EDAC MC: Ver: 3.0.0
Advanced Linux Sound Architecture Driver Initialized.
clocksource: Switched to clocksource arm_global_timer
NET: Registered protocol family 2
TCP established hash table entries: 2048 (order: 1, 8192 bytes)
TCP bind hash table entries: 2048 (order: 2, 16384 bytes)
TCP: Hash tables configured (established 2048 bind 2048)
UDP hash table entries: 256 (order: 1, 8192 bytes)
UDP-Lite hash table entries: 256 (order: 1, 8192 bytes)
NET: Registered protocol family 1
RPC: Registered named UNIX socket transport module.
RPC: Registered udp transport module.
RPC: Registered tcp transport module.
RPC: Registered tcp NFSv4.1 backchannel transport module.
hw perfevents: enabled with armv7_cortex_a9 PMU driver, 7 counters available
futex hash table entries: 512 (order: 3, 32768 bytes)
workingset: timestamp_bits=28 max_order=16 bucket_order=0
jffs2: version 2.2. (NAND) (SUMMARY)  © 2001-2006 Red Hat, Inc.
io scheduler noop registered
io scheduler deadline registered
io scheduler cfq registered (default)
dma-pl330 f8003000.dmac: Loaded driver for PL330 DMAC-241330
dma-pl330 f8003000.dmac:        DBUFF-128x8bytes Num_Chans-8 Num_Peri-4 Num_Events-16
42c00000.serial: ttyUL2 at MMIO 0x42c00000 (irq = 166, base_baud = 0) is a uartlite
e0000000.serial: ttyPS1 at MMIO 0xe0000000 (irq = 144, base_baud = 3124996) is a xuartps
e0001000.serial: ttyPS0 at MMIO 0xe0001000 (irq = 145, base_baud = 3124996) is a xuartps
console [ttyPS0] enabled
xdevcfg f8007000.devcfg: ioremap 0xf8007000 to d0872000
[drm] Initialized drm 1.1.0 20060810
brd: module loaded
loop: module loaded
CAN device driver interface
gpiod_set_value: invalid GPIO
libphy: MACB_mii_bus: probed
macb e000b000.ethernet eth0: Cadence GEM rev 0x00020118 at 0xe000b000 irq 148 (00:0a:35:00:01:22)
ICPlus IP101A/G e000b000.etherne:00: attached PHY driver [ICPlus IP101A/G] (mii_bus:phy_addr=e000b000.etherne:00, irq=-1)
e1000e: Intel(R) PRO/1000 Network Driver - 3.2.6-k
e1000e: Copyright(c) 1999 - 2015 Intel Corporation.
ehci_hcd: USB 2.0 'Enhanced' Host Controller (EHCI) Driver
ehci-pci: EHCI PCI platform driver
usbcore: registered new interface driver usb-storage
mousedev: PS/2 mouse device common for all mice
i2c /dev entries driver
rtc-pcf8563 0-0051: chip found, driver version 0.4.4
rtc-pcf8563 0-0051: pcf8563_write_block_data: err=-11 addr=0e, data=03
rtc-pcf8563 0-0051: pcf8563_probe: write error
rtc-pcf8563: probe of 0-0051 failed with error -5
cdns-i2c e0004000.i2c: 400 kHz mmio e0004000 irq 141
EDAC MC: ECC not enabled
Xilinx Zynq CpuIdle Driver started
sdhci: Secure Digital Host Controller Interface driver
sdhci: Copyright(c) Pierre Ossman
sdhci-pltfm: SDHCI platform and OF driver helper
mmc0: SDHCI controller on e0100000.sdhci [e0100000.sdhci] using DMA
ledtrig-cpu: registered to indicate activity on CPUs
usbcore: registered new interface driver usbhid
usbhid: USB HID core driver
nand: device found, Manufacturer ID: 0xef, Chip ID: 0xf1
nand: Unknown W29N01HV
nand: 128 MiB, SLC, erase size: 128 KiB, page size: 2048, OOB size: 64
Bad block table found at page 65472, version 0x01
Bad block table found at page 65408, version 0x01
nand_read_bbt: bad block at 0x000007f60000
nand_read_bbt: bad block at 0x000007f80000
nand_read_bbt: bad block at 0x000007fa0000
nand_read_bbt: bad block at 0x000007fc0000
6 ofpart partitions found on MTD device pl35x-nand
Creating 6 MTD partitions on "pl35x-nand":
0x000000000000-0x000000300000 : "nand-fsbl-uboot"
0x000000300000-0x000000800000 : "nand-linux"
0x000000800000-0x000000820000 : "nand-device-tree"
0x000000820000-0x000001220000 : "nand-rootfs"
0x000001220000-0x000002220000 : "nand-jffs2"
0x000002220000-0x000008000000 : "nand-bitstream"
NET: Registered protocol family 10
sit: IPv6 over IPv4 tunneling driver
NET: Registered protocol family 17
can: controller area network core (rev 20120528 abi 9)
NET: Registered protocol family 29
can: raw protocol (rev 20120528)
can: broadcast manager protocol (rev 20120528 t)
can: netlink gateway (rev 20130117) max_hops=1
Registering SWP/SWPB emulation handler
hctosys: unable to open rtc device (rtc0)
ALSA device list:
  No soundcards found.
Waiting for root device /dev/mtdblock6...
`
-------------------------------------------------------------------------------------

I've tried changing the root device to mtdblock5 but this just gives the following

-------------------------------------------------------------------------------------------
`
U-Boot 2015.07 (May 18 2017 - 22:22:09 +0800)

Model: Zynq Zed Development Board
DRAM:  ECC disabled 256 MiB
NAND:  128 MiB
MMC:   zynq_sdhci: 0
Invalid bus 0 (err=-1)
*** Warning - spi_flash_probe() failed, using default environment

In:    serial
Out:   serial
Err:   serial
Model: Zynq Zed Development Board
Net:   Gem.e000b000
Hit 'd' to stop autoboot(eric): 0
zynq-uboot> setenv nandboot "echo Copying Linux from NAND flash to RAM... && nand info && run nandroot;nand read 0x100000 0x2220000 0x300000 && fpga loadb 0 0x100000 0x300000 && nand read ${kernel_load_address} 0x300000 ${kernel_size} && nand read ${devicetree_load_address} 0x800000 ${devicetree_size}"
zynq-uboot> run nandboot
Copying Linux from NAND flash to RAM...
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

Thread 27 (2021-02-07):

PYNQ build

dinosauria123, 2021-02-07:
I have found how to build PYNQ for EBAZ4205.

https://webuiltawallwebuiltthepyramids.blogspot.com/2021/01/yet-another-ebaz4205-writeup-3-pynq.html

That’s interesting. Please add it to the wiki.

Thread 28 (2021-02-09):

Weird characters in UART

Guillermo-Ramirez-Jimenez, 2021-02-09:
Hi,
recently, I got one of these boards and I tried to have a look at the SSH in UART. Unfortunately, I get some mixed right and wrong characters.

I tried 2 different USB to TTL converters and cables, but the issue is still there. 115200 bauds.

Am I missing any particular option for the serial connection?

Here you have a sample of the output:

```

.c⸮⸮⸮f⸮⸮⸮ ⸮⸮"Mcs'dv⸮/2fz⸮ֱ⸮⸮"⸮O3⸮⸮/_⸮^g⸮⸮⸮do&⸮ i⸮ɨ⸮/wv⸮⸮ ⸮w⸮⸮f⸮~⸮⸮⸮⸮-1)
*** Warning - spi_flash_pr⸮be(+$ocZ_6⸮"⸮smgd⸮g⸮|7~⸮z⸮⸮o{vs⸮zl⸮g⸮⸮n⸮⸮⸮⸮?⸮w⸮⸮ ⸮lv⸮⸮2⸮l6w⸮n⸮nz]⸮"⸮⸮v/⸮⸮⸮чcu_⸮⸮⸮;⸮ g~f⸮⸮⸮⸮ h⸮⸮她⸮⸮Linux from NAND flash to⸮⸮⸮⸮⸮٭⸮7*D⸮vz⸮6
⸮⸮ ⸮d⸮o⸮⸮c ٧sۿ6?⸮ƃz⸮bm36 ⸮⸮⸮⸮⸮b⸮⸮⸮⸮߻睿⸮w⸮⸮2⸮n6⸮⸮2fc'v{⸮խ⸮nsL$V ⸮⸮v⸮f⸮~ ~⸮⸮⸮⸮⸮⸮j

NAND read: device 0 offset 0x2⸮&f¢f ⸮⸮z[lf32⸮f ⸮v⸮⸮⸮⸮⸮>⸮⸮⸮yg⸮l;⸮⸮⸮{⸮n⸮⸮⸮⸮⸮⸮⸮⸮z{ v⸮
⸮{t⸮⸮W⸮Vv⸮⸮⸮e⸮⸮~f⸮⸮⸮&⸮00000, size 0x500000
"w'⸮⸮⸮#b ⸮⸮#v⸮c⸮7⸮⸮x⸮⸮ 131072 bytes read: OK
## Bootkng kernel⸮⸮⸮⸮wgg⸮s^l⸮o⸮⸮#⸮&⸮&f26⸮f⸮>.
*⸮Lr⸮⸮⸮⸮⸮>c⸮t⸮]⸮Ց⸮?nnf⸮7⸮⸮d⸮~{gv f⸮>⸮L3⸮" {⸮w⸮o⸮⸮f⸮⸮⸮⸮⸮ ⸮⸮⸮j
   Entry Point:  00008000
 ` veri⸮^⸮⸮9⸮⸮⸮⸮⸮o⸮r⸮⸮O⸮⸮3d⸮n{ w˝⸮"⸮ wkg⸮wn⸮f⸮⸮⸮"e⸮ ⸮7⸮vw⸮⸮⸮⸮~&n?.⸮   Loading Device ⸮ree to ⸮⸮v⸮⸮⸮l;;⸮⸮ ⸮⸮w⸮6⸮2d⸮⸮;z/ nc⸮wcv⸮k⸮ ~⸮⸮⸮⸮⸮⸮ߥs⸮O>aU&⸮own⸮ou⸮dwo⸮⸮ nj⸮⸮⸮{m⸮^;",⸮⸮⸮Fg_⸮g ⸮⸮⸮	J  ⸮ ⸮5A⸮PREEMPT Mon May 8 14:36:49(Cs⸮f_⸮n- w⸮⸮s⸮w⸮⸮n⸮sg⸮⸮k⸮_⸮3⸮o⸮ w⸮⸮|⸮Vo⸮⸮>f⸮V77*⸮{g⸮^⸮/~⸮svw⸮{o0gx,⸮⸮⸮?㟷⸮⸮⸮⸮~⸮⸮⸮⸮ ⸮Y⸮⸮ٕ⸮⸮16 MiB at 0x0e000000
Memor^H⸮⸮⸮Q,⸮ /⸮⸮⸮ ͽ⸮⸮g⸮⸮⸮?.⸮ۿsw⸮LvKg⸮⸮ ⸮?⸮⸮⸮鿽g⸮v⸮⸮r⸮l⸮ k⸮~w⸮w⸮⸮⸮⸮n6{⸮⸮ ⸮}⸮⸮⸮⸮⸮⸮⸮~⸮⸮⸮⸮⸮ne: console=ttyPS0,115200 root=/dev/mtdbl⸮so⸮$⸮⸮⸮st~⸮ ۛ⸮s⸮⸮⸮⸮~⸮⸮.v⸮݃roov⸮o⸮⸮⸮w⸮?+⸮⸮⸮me⸮⸮⸮so{.⸮32⸮⸮⸮;o⸮ֶ;$oOr⸮⸮ƻ⸮⸮⸮⸮⸮⸮⸮vn⸮⸮⸮⸮v ⸮⸮⸮⸮⸮⸮⸮ 16384 (order: 4, 65536 bytes)
sY[K⸮⸮⸮2.⸮⸮wZ⸮⸮6⸮n3[fz߷⸮g⸮ 6O⸮⸮⸮6⸮z⸮⸮⸮⸮⸮⸮⸮⸮⸮⸮⸮⸮M⸮⸮⸮⸮Ooֽ⸮⸮r۾⸮⸮7⸮3⸮o2⸮~6⸮gm⸮/n⸮k⸮⸮]X_⸮⸮⸮⸮⸮⸮⸮ ⸮⸮⸮⸮⸮⸮ : 0xffff0000 - 0xffff1000   (⸮"`4"oB;
⸮H2
2⸮zmznvo&⸮zfcv⸮fw"m|f⸮⸮f⸮Lw⸮"⸮f 6⸮⸮⸮^'vӍ⸮0v⸮&s3o⸮f⸮2v⸮&72f⸮$eo⸮⸮⸮O⸮N⸮ f⸮⸮⸮n ⸮⸮f⸮⸮⸮⸮⸮⸮⸮&  B   ⸮ j	⸮
    modules : ⸮⸮⸮⸮0000p0/`0z⸮⸮6 ⸮⸮⸮"⸮NgV⸮⸮⸮o⸮nr⸮f+2r⸮⸮⸮١; ⸮⸮~7w3⸮\ VB⸮⸮2t⸮{fjv⸮#⸮|&⸮⸮⸮⸮c`⸮d7cp⸮24⸮⸮W[Ff⸮ ;⸮⸮⸮⸮ff~f⸮⸮⸮⸮,'⸮⸮939e60 - 0xc0972764   ( 227 kF)
 ⸮⸮{_nyf⸮]vo⸮⸮sv⸮⸮{o⸮⸮⸮Gw⸮on{_⸮ϝ ⸮⸮⸮⸮⸮⸮⸮>⸮Ko{L⸮⸮7sWs_m6$⸮⸮⸮⸮w⸮f⸮v5.v⸮⸮⸮Ad⸮ ⸮fV⸮⸮ ⸮⸮⸮⸮⸮32, nr_cpu_ids=2
NR_IRQS:16 nr_irqs:q7 5> N{V⸮gd nwg⸮⸮⸮;"⸮⸮6⸮Lf : sv⸮+⸮r⸮2⸮3⸮7⸮2⸮^⸮⸮⸮⸮擲w;N⸮*⸮vto⸮⸮⸮fO⸮⸮⸮o⸮/v⸮݃cuy`g⸮⸮⸮⸮⸮⸮⸮ ⸮⸮⸮⸮⸮⸮⸮⸮⸮⸮⸮⸮j
L2C-310 erratum 769419 Y+⸮⸮u
⸮⸮⸮k⸮⸮⸮g⸮~6?nV;⸮⸮;⸮f⸮w7 3⸮~⸮⸮v⸮ ⸮⸮w⸮⸮⸮⸮⸮&Ygf⸮wv⸮"of⸮vdNf;~e⸮v72gO⸮3 "⸮n⸮{⸮⸮gn⸮ ⸮⸮⸮ ⸮⸮߷⸮ *⸮⸮⸮⸮⸮⸮5
L2C-310 cache control⸮ev⸮en⸮bn⸮Y ⸮dW⸮⸮>d l7o⸮7;N⸮⸮⸮⸮⸮⸮3gr>⸮⸮⸮ ⸮t~⸮⸮3f⸮⸮⸮⸮⸮~u⸮,⸮o⸮⸮⸮n{_⸮jg⸮_⸮5⸮⸮so⸮n3⸮fZ].-⸮⸮⸮⸮⸮⸮⸮⸮⸮⸮ ⸮⸮⸮⸮⸮⸮⸮398046511103ns
clocksource: arm_gloram t⸮oe⸮:d ⸮⸮of⸮x⸮⸮⸮f⸮⸮⸮f⸮⸮⸮oe⸮ ogl ⸮⸮ g⸮|v6o⸮~op,⸮⸮⸮ l ⸮⸮ϑ⸮~wg⸮vso ⸮VKf⸮⸮⸮7⸮g⸮⸮w⸮g⸮⸮⸮⸮ycles: 0xffff, max_idle_ns: 537538<77 nsc3w⸮⸮⸮⸮#⸮Lv2f⸮Ns⸮⸮⸮?&z⸮w⸮7s⸮⸮⸮ݿ⸮⸮⸮⸮⸮⸮⸮⸮⸮⸮}6
⸮ߥ~g⸮vm ⸮W⸮⸮ws_ ⸮⸮>⸮n⸮r⸮⸮"F⸮g⸮⸮
⸮e⸮⸮⸮⸮⸮⸮⸮⸮⸮⸮⸮'⸮⸮⸮⸮⸮ j⸮⸮⸮⸮յ⸮ 301
Mount-cacje jasj`⸮,6⸮⸮⸮~t⸮~⸮>'v⸮⸮⸮3jK⸮⸮r~~f;⸮⸮7$⸮/wݽw⸮⸮⸮⸮~⸮⸮⸮g⸮⸮mɭ⸮⸮&⸮⸮⸮⸮v⸮⸮ ⸮v{⸮⸮vdo=⸮(wU⸮Fﾕ⸮⸮⸮ ⸮o⸮⸮󂂂⸮⸮⸮⸮j
Setting up static identity map`⸮ov⸮0⸮Lf3⸮⸮⸮?⸮n⸮Lf⸮>⸮.Uw⸮⸮w⸮⸮V6 ⸮6⸮⸮⸮⸮⸮⸮⸮⸮swOݥsg⸮ow⸮⸮⸮"⸮~⸮⸮⸮⸮2⸮⸮7{t⸮N⸮Lt⸮w⸮⸮v⸮fvW⸮⸮~⸮⸮⸮⸮⸮ѵ⸮⸮⸮⸮ initialized
VFP support ⸮Ly⸮ N⸮ѳս⸮⸮vob⸮lvoc⸮~wot ⸮6o ⸮yv⸮⸮fbv^⸮⸮⸮⸮f⸮⸮ ⸮c⸮⸮⸮⸮g⸮o⸮⸮3⸮Nf⸮2⸮O⸮⸮⸮3W⸮⸮⸮nw
*⸮?⸮⸮⸮⸮⸮g⸮⸮⸮⸮⸮⸮⸮⸮⸮⸮⸮ѕ⸮5
NET: Registered protocon`fcminy⸮LsHD7C~⸮nwo⸮⸮ cxWv0⸮  ⸮.⸮⸮so⸮⸮⸮ r\⸮⸮⸮⸮⸮ ⸮⸮⸮ݻf&_n{/3⸮⸮w[>w⸮/⸮>w/o⸮⸮⸮⸮d{⸮⸮Ł⸮|⸮⸮⸮⸮~]LW⸮ ⸮⸮⸮⸮⸮H[X⸮⸮յ⸮watchpoint size is 4 bytes.
*z⸮nq⸮og⸮ f⸮2⸮>f⸮. o  ⸮gn⸮l
w2⸮ol; ⸮Ow⸮⸮⸮⸮⸮⸮wvn⸮O"⸮ e⸮ vnv=⸮i~⸮⸮o⸮⸮ѝ⸮#k⸮~wo⸮⸮ze⸮⸮⸮wf _⸮⸮~⸮⸮⸮⸮ٕɁusbfs
usbcore: registered new z⸮⸮ə⸮⸮⸮⸮⸮rz׶⸮n ⸮⸮⸮w⸮⸮⸮~⸮⸮⸮ow⸮]⸮⸮⸮⸮⸮⸮ o⸮⸮re1k⸮⸮gv⸮s⸮~⸮2⸮⸮⸮x$⸮⸮ ⸮s⸮⸮$;⸮⸮r⸮*V^m⸮w⸮⸮vwv⸮ w ⸮w⸮⸮⸮ftware ver. 5.3.6 - Copyright 2405-⸮04⸮ v⸮⸮⸮fo⸮T⸮⸮⸮⸮wi^>⸮ o{}wo⸮z⸮⸮?o⸮jV⸮⸮⸮⸮⸮⸮g⸮v_⸮gg⸮_⸮O3⸮⸮v{>v⸮o⸮~n+z⸮_⸮J6⸮⸮⸮ͽ⸮͍⸮⸮d⸮ t?⸮⸮⸮⸮⸮ ⸮⸮E⸮⸮⸮⸮5
NET: Registered protocol gamily!2S⸮⸮T .⸮ve⸮~o⸮z⸮ $;s⸮nw⸮⸮⸮w⸮ ⸮⸮⸮⸮⸮6⸮⸮f⸮⸮⸮⸮⸮l⸮f⸮2 {v{⸮⸮lf?r~~⸮⸮zf⸮|6⸮݇so⸮V⸮V⸮wρ~⸮w⸮f_⸮⸮⸮⸮g⸮⸮⸮͡⸮table entries: 256 (order: L	Ɗʖ⸮ ⸮ѝ⸮⸮ ⸮w6⸮r⸮⸮6
g{$⸮~.⸮d[t⸮~⸮⸮ ⸮?>⸮⸮⸮⸮g⸮ρ⸮c[{ v⸮⸮:7⸮⸮so{7vr⸮o⸮⸮rvJ⸮⸮wn{⸮zdE⸮⸮⸮⸮⸮⸮o⸮ ⸮ ⸮ ⸮⸮⸮^H 5⸮ Registered tcp transport mo⸮ulm.
⸮*⸮('⸮⸮⸮voٷ⸮g⸮l⸮o⸮ ⸮w⸮⸮;"fz⸮⸮ g⸮⸮fv⸮n⸮⸮⸮֦3o⸮׽t{⸮nvv⸮z⸮⸮n⸮cgvt⸮~2+s⸮LW⸮
⸮O⸮⸮}v⸮ ⸮⸮⸮~|⸮⸮⸮⸮⸮X⸮ɭ⸮⸮⸮͕⸮⸮ timestamp_bits=28 mcx_ordgvOf7Mկ{e⸮⸮⸮fe⸮⸮w:⸮⸮⸮⸮:f⸮⸮⸮{o⸮L⸮M⸮⸮:⸮y⸮⸮⸮⸮s⸮⸮ ⸮⸮⸮g⸮_⸮o⸮⸮]v_⸮⸮ՙ⸮wgz.wo⸮⸮u
Z⸮⸮~⸮⸮w_}w⸮f~⸮⸮⸮[[XK⸮⸮30 f8003000.dmac: Loaded drives f⸮rd⸮nw'f ⸮;o?⸮O⸮⸮2s1w;/⸮{⸮⸮&⸮Nfד⸮⸮⸮o⸮⸮⸮⸮⸮⸮{e⸮ ⸮⸮⸮w 2~~7⸮⸮'_fNo⸮ ⸮⸮22^h;oՃ=$L⸮3M⸮⸮wgeg_⸮v~⸮⸮⸮⸮⸮⸮⸮⸮⸮r⸮⸮ɥ⸮⸮⸮ ttyPS1 at MMIO 0xe00800⸮Ld)⸮⸮⸮?⸮L3⸮&⸮|w⸮e⸮⸮⸮?f⸮⸮⸮⸮'⸮k⸮Xn⸮~ w⸮v⸮2⸮⸮6⸮NgWMn⸮2Zn⸮|n sm⸮⸮⸮so  ⸮g⸮⸮pS1 d⸮~⸮|⸮⸮⸮ ⸮⸮⸮⸮⸮⸮,֖ J⸮ɕ⸮⸮⸮⸮0xf8007000 to d0876004⸮ [d⸮_⸮o⸮⸮~m⸮ v⸮⸮⸮07⸮f;0v~&7º⸮{⸮⸮⸮ ⸮⸮ o ⸮⸮⸮⸮⸮ o⸮gv⸮⸮ e⸮|;⸮⸮⸮⸮⸮?⸮⸮pmf_⸮6g⸮⸮w{7⸮⸮⸮⸮⸮/v:s' M⸮l ~ ⸮⸮⸮o⸮⸮⸮C⸮}⸮⸮Y⸮⸮ ⸮00.ethernet eth0: Cadence GEM ⸮Y
⸮⸮⸮0⸮L⸮:${_v⸮g⸮f⸮O⸮⸮"o⸮~v⸮g⸮0⸮'⸮O⸮⸮⸮⸮⸮⸮⸮⸮>⸮⸮⸮ ⸮⸮&w⸮⸮? dj⸮⸮_⸮ n⸮z^5⸮⸮r⸮yn⸮ ⸮⸮⸮n⸮t⸮߻⸮⸮⸮⸮⸮⸮⸮⸮
I⸮ ⸮I=⸮1000 Network Driver -(3.⸮⸮n{
⸮]fS⸮.⸮ ⸮⸮⸮⸮ ot⸮⸮⸮?⸮⸮9&⸮Nfq7⸮v⸮W⸮ ⸮⸮⸮⸮w⸮vn frm⸮⸮wNt⸮⸮⸮vK"n⸮⸮
⸮ ;vWg⸮⸮۵⸮⸮⸮m⸮⸮wof⸮⸮g~⸮⸮⸮⸮⸮⸮⸮driver usb-storage
m⸮ͷ⸮⸮⸮$⸮[2o⸮ݷ3f{o⸮>⸮ｷ n⸮⸮["lo⸮⸮⸮⸮⸮o_d⸮J⸮Wٷ⸮2⸮}⸮w ⸮n⸮⸮⸮⸮u>r⸮  ⸮⸮⸮⸮⸮⸮⸮ ⸮⸮⸮⸮563_write_block_data: evr=-91$x]⸮?6{Od/ٷ?4 n⸮⸮vO⸮⸮;7⸮&v?6⸮MM/⸮=⸮ ⸮⸮⸮⸮⸮u =⸮⸮⸮k⸮?⸮/⸮⸮⸮0⸮nj⸮s⸮n310 ⸮⸮omo$e⸮⸮ކ⸮⸮⸮ ⸮⸮ ~EDAC MC: ECC not enabled-JXZ[m
⸮⸮^⸮W:⸮⸮O⸮ 6⸮g⸮߶⸮w⸮~nw⸮⸮sd~⸮⸮2o⸮⸮r⸮]⸮nͷ⸮nS⸮nOgZo7⸮f['⸮ ⸮⸮g&⸮ ,⸮⸮[⸮dZ⸮⸮F⸮⸮⸮⸮⸮⸮⸮⸮⸮⸮⸮?⸮E!
%⸮controller on e0100000.sdxci0[YL&S⸮⸮⸮.w⸮jg⸮ ⸮}⸮⸮g⸮w⸮⸮⸮⸮⸮ {⸮ϕ⸮ag⸮ow⸮⸮⸮onn(w7=ou.⸮⸮K⸮⸮ registered new interface drm⸮ev⸮]n<⸮⸮u. >6/⸮⸮ug⸮⸮ ⸮nq~f⸮⸮⸮⸮⸮,W⸮⸮ɁID: 0xef, Chip ID: 0xf1
⸮~⸮ 2⸮⸮o⸮w⸮n⸮⸮~⸮N)⸮⸮⸮f⸮⸮3⸮ ⸮'⸮⸮k⸮ g⸮⸮nofX]⸮⸮⸮ ⸮~⸮⸮472, version 0x01
fZ}⸮ｿ⸮d⸮~v⸮$⸮⸮ff^⸮v⸮⸮Ù⸮L⸮⸮f'gY ⸮⸮⸮⸮f{{⸮⸮ooO ⸮ ⸮~fW⸮⸮⸮6⸮Lw⸮ ⸮g ⸮⸮⸮⸮⸮00007fa0000
nand_read_bbt: bad`bno⸮kh|]v⸮⸮撢⸮7f<Lw⸮~/;⸮⸮ӧs⸮~⸮⸮wm⸮^⸮o⸮⸮ u⸮⸮⸮⸮~M⸮fǊ⸮⸮⸮6⸮Lw⸮{&⸮⸮2⸮l⸮⸮t⸮LwK 6⸮⸮⸮ѵ2⸮b⸮⸮⸮ _⸮ p~L⸮򂂂j⸮⸮⸮00000800000 : "nand-linux"
t⸮2⸮NfNgW⸮⸮⸮/⸮~7w⸮⸮⸮:⸮NfW⸮⸮⸮⸮v>⸮ ⸮⸮⸮s&c⸮p⸮2⸮⸮⸮⸮⸮000002220000 : "nand-jffs2"
⸮~⸮Ls2v⸮&w2v{lo0v⸮N⸮ײ⸮⸮⸮⸮gd⸮ ⸮~⸮Lf⸮6e30⸮l&⸮⸮v⸮c⸮ ⸮⸮nvo⸮⸮fG⸮⸮?fw⸮⸮⸮g4⸮lw⸮⸮f#nz⸮⸮rg⸮_⸮ՙw;t⸮⸮⸮nsw ⸮⸮⸮yw⸮⸮⸮w⸮ve⸮⸮
gѧt⸮⸮⸮⸮k⸮o&⸮kv{wz⸮NET: Registmred pzotoco⸮HvV⸮⸮⸮^⸮X⸮⸮c{#⸮⸮⸮⸮^G⸮'⸮W⸮⸮⸮v{⸮6
⸮⸮ vko⸮&v⸮o⸮^⸮{ ⸮c|⸮|⸮⸮B⸮⸮ف20120528)
⸮cn;"f⸮⸮⸮c⸮?7⸮c⸮~v⸮"⸮⸮⸮c⸮2⸮⸮⸮⸮rtn3⸮⸮ ⸮⸮ ⸮⸮3
⸮⸮g+⸮⸮⸮r⸮g^⸮w⸮⸮⸮~⸮⸮⸮⸮>⸮k g⸮⸮a⸮ 6⸮⸮⸮⸮p⸮⸮⸮⸮ ⸮⸮  ⸮⸮⸮⸮v⸮fw⸮⸮⸮w3⸮⸮⸮⸮⸮f⸮⸮⸮⸮?⸮⸮v⸮ٻ⸮^:⸮s?⸮ ⸮⸮ ⸮0~⸮&⸮Mw⸮⸮⸮wwwn⸮⸮⸮⸮fn⸮⸮ ⸮⸮|g⸮⸮⸮v⸮⸮⸮⸮⸮⸮⸮1528000
⸮⸮   w "⸮⸮⸮⸮}rf⸮⸮⸮7gx ^"7⸮}⸮v⸮⸮׳o:⸮m?ߗ⸮⸮w3_b~⸮ ,r⸮⸮⸮⸮⸮73?⸮ ⸮⸮⸮wuw3w|⸮֛⸮⸮ ⸮}s57⸮⸮⸮⸮w⸮⸮ ⸮⸮w;#⸮q3⸮2^Y3#^⸮/NtE⸮3ww⸮⸮n⸮3⸮⸮2⸮3⸮l⸮⸮ ⸮⸮rd⸮⸮3⸮⸮w⸮⸮⸮⸮ R⸮t#}⸮yE~⸮gye~⸮g⸮'~⸮gyG~⸮g⸮G^D⸮, ⸮D⸮⸮ ⸮E}@~~⸮~⸮⸮⸮⸮!  w⸮w7ww⸮⸮v⸮   Freeing unused kmrn{[䫽⸮⸮⸮⸮⸮3⸮6⸮ ⸮>3<⸮lw3 {lv;r⸮lw; ⸮ ⸮⸮⸮w⸮⸮e{⸮~⸮'{e~⸮~⸮׻⸮⸮⸮w⸮⸮׻⸮wߺ6Mf⸮L( b d⸮⸮~pg⸮⸮⸮~⸮~⸮⸮⸮⸮⸮⸮⸮⸮⸮ww⸮Ϳ⸮׻⸮⸮gN⸮⸮⸮o2g⸮&v'>{B~⸮N6⸮e}Btߺ⸮⸮⸮~⸮ ⸮⸮ y y y y y y y y y y y y y y y y!y {Ay y {E~⸮ {Eb⸮⸮⸮⸮⸮7⸮⸮⸮w⸮⸮⸮g gw⸮⸮G⸮? 67?⸮⸮{⸮⸮⸮⸮7⸮⸮?.n⸮n2⸮⸮⸮o/ ⸮⸮⸮n2?3f⸮$⸮'77⸮⸮ww⸮⸮⸮⸮⸮⸮⸮⸮⸮f"D@Dd⸮f$f$&bDdffff f Fd&f FF&f$
```

nic3-14159, 2021-02-10:
Which software are you using to connect, and do you know the model of the USB to TTY converter you are using?

Guillermo-Ramirez-Jimenez, 2021-02-10:
First, I tried with Arduino IDE on Windows, then with Minicom on a Ubuntu VM. The converters are a PL2303 and a FTDI232.

I think it may be a config issue in Windows, data bits, parity, control flow, etc. I'm using the default options but I may need to change something.

nic3-14159, 2021-02-10:
The options I have are 8 data bits, no parity, and 1 stop bit (shows up as 8N1 at the bottom of Minicom). Maybe also check that the converters are set for 3.3V and not 5V? If those don't work, maybe try another terminal software, such as HyperTerminal or PuTTY

Guillermo-Ramirez-Jimenez, 2021-02-10:
Thanks but nope. I checked everything and tried PuTTY but I still get the same.

Here's the log:

```
=~=~=~=~=~=~=~=~=~=~=~= PuTTY log 2021.02.10 02:41:03 =~=~=~=~=~=~=~=~=~=~=~=

1.0.0.47 (De,¢ú ²ÆšºÁ/ô1t367lçnw;Oôvwû~ÿfç~f÷ö÷g cÆvgÿv~ÿ÷fÿw~f?¶ßn¦w;î:$wûþ  ö³þÿþÿ«™…Õ±Ñenvironment

In:    seriaì
JOut; ðHîOµç~ã£¶>·2ô¾¶¿vÿæwÿ¶ û…~~w~ÿf÷÷ÿv?LÆÇ3ûf7lw/f'#þ¿v¾ãûoçôwo«xô–ÿöûÿöÿX‹Á, sector size 128 KiB
  Page skze ðH$I"Ö’¢å ÷vÇ3ûn³¿ÿ²~îvo& 3ÿ¢FâO2ç¿þÿ÷·>>v2?vún2»~d ²ã&w îgg>ç ‘wo‘û&ÿÿþþ 6öÁ00
17þ»ÿ2||¬÷g6 odÝäz÷ þþ ·gÿ~ì ²·ÿf÷»&þ¾wfw3þ|î gôLï“¦Ç2þöÿ ÿ>“ÂÂ‚  åÑ•Íread: OK

NAND read: dgvic÷Hfï™»sÿ$ü~ç2ö|&?¾·¿6Oòÿ2þ~æ|üLö&÷2l· ww¶¿v¿>´õw: & ÿ÷fÿL&Â‚‚‚‚ rrrj
   Image Name:   Linux-4.6.0k^ÛoË+?Ç$r/¿çg?òçþöâöþ¶÷s¶~»ú$w»wûöÿv{¾÷#þNf'w2off|·»v~l÷/¹÷:dLw2þ~w¾ ~v_ÏöTree blob at 02000000
   Booting uséng thå ³Y7Oþfô~úfû2º|&·v&vÿoxVûgþÿÿÿ~÷ d~vþ¿ÿ&æû	2Í03b90 ... OK

Starting kernel ...M
 ÇÃo¯oÿö÷ ÷ öþersion 4.6.0-xilinx (root@alvin) (gkc »Yî¯½»Á7·&;"ü ~³ ¶üþ:7ó ÷ïwnwú¿²~ þÿÿÿ ¶|<w³|ïºç7fw³6w¿|¾:g´$ÿvn7Í¿¿cþ~ö ÿ~öÿçþÕÑ¥½¹cache
Machine model: xlnx,zynq-00øGá­ë"v{¾¶ÿg{´÷"O~>öþf ?w ¦Çrúþ þÿÿ &7o7þ»û&7¦ÿ,¶¶w"÷ýÏ²w#tål ¤ þÿÿö~ þ®«Á¥¹on.  Total pages: 65024
Kernel coíoaïdô m¿>ô¿»ÿ³ ¾ þ>7ûî&f ~ÿþÿf÷þÿ÷ÿ~f>3vv ¶÷"þo&ç;ÿ~ö÷g¿v7g÷ îÇ??÷fçÿ•Éé 5, 131072 bytes)
Inode-cache hash tx,»O:¿vvzÿ÷2w3¼ÿfûó³ >çw· sw›öÇföÿ÷ç?$÷çþ~f36>Oö ;ï±çr»ûdowö¤w3wúöçöÿóÿ¥¡µ•µ¥
Virtual kernel memory layout;-N! `!veót &´76?¶ÿfþlw¦³nf·Lw2lþfç~ÿ  þ>? ÒÆç3º|ä;âóÿf¼|&&7?²FÇ7ÿ&äj÷nfçfvÿH B ’ª² j	¥
    pkmap   : 0xbfe00000$kHfÍÑØL72¼|dv³ülfvg»æfç3¶ ³ µÏ"~w~vf>oÏ2wö?t¯äçs&~L¶onz¿ö"v~>w24Lf7ïfÏþ  þ~w~ ‚ÂÁ900000 - 0xc0939e60   ( 232 kB)
J  `  `0.·¾w "æ~v·æ?þäç&¿öÿ37¿3vOf>÷~þL»Å~û~7ÿw·wþn÷?ºöþv'÷þ'öõsþ¾ûþö ¶s=2.
RCU: Adjusting geometry for rcußfan uþÅ·c÷ofw ÷¾¿Çw ~öw2¿æû {¿tnÇvþÿ ÷ÿþÿÿ${f{o{~vÿ~~¾û»¿þfçg~~wKùÇ2¼“ÿvþ~wÿ~þõmodifies aux control register: 0x“š¶‚‚†Á û Æ¿·²çn7òw¦v ¿ç3þög¾];ï²?þ?öÿ»7·ïo¶· bö 6ÿ ÿN÷ tû~n·Ù¼'>õw~L ÿöþþÿþÿ1ÉC-310 dynamic clock gating enabled,$>Wö™ç mÏ—çg¿|lûn¾Ìû ?Ç2²¿î gô¾û ÷~ÿÿv¾|®úN ~¿þoo ~o gòÏ½ÿ"óãr¾nvôô»þ~÷~÷þk: 64 bits at 333MHz, resolution 3ns, wraðs`õv× ôMwgwºî¦þ7ÿsÿÿoowëÙÿÿÿ~þÿÿ~ÿçÿï0þOî··w»î²Fÿwó³ÿ~÷  · dÿ$¾~÷þÿþþHh±½­Í½ÕÉ•é ttc_clocksource: mask> 0|fff÷HÛxÿ=o÷÷d¾~¶öæþ~¿ï ÿ ûçßíbþ÷~÷ÿw¦t§~o÷¾vûno2 {#lïÑç:ÿût¼]vÏ&ÿgö~ÿçö÷ÿ¹ 666.66 BogoMIPS (lpj=3333330)
pid_max:`ôgfñwö §3væ§ÿo÷ÿ÷~ö&wv? w÷÷ûç ÿöþwÿ>l»$ût¿~÷'ä&fLç{fû>gvò§£ÎÙ$÷~wÿwç~ÿÿþÿkåé ok
CPU0: thread -1, cpu 0, socke| 4ÖHÛûdýdÇ2¼|f7?çº6ÿoûb>ä ct~l fÿvÿÿÿÿ×ï2tþæw|2ÿw v~tü&ö/÷?N÷GëÁtÏ• öÿfÿ~ÿçÔë½5%AM¥.
CPU: All CPU(s) started!in!sVÃ [Ï—ý ç ¶÷ ¼wî¿ w ~û¿vòöÆtôÿÿÿÿþ÷{2·~¶vÿï"?s 2¾~·ÿf÷f÷L§ç g~l2w÷÷Ù2750000 ns
pinctrl core: initializmd ¸^{ÏÙ³"w ¾wó¾ OæO oöw ?óv t¾ógÿf~ö~òwû¾û'v¾ïdïv{>ûod{n G:ï½Ïro~ÿÿ÷;öÿ®+Ë‹and 1 watchpoint registers.
hw-brgaëpoént'ä?zûÿûlwÿwö¿§vú¿ÿ}äodÿf ÿÿóþ>‘ÿ3þ¹ûc¾?ûçzÿsö~o{vÿ äûoñåcû ÿþÿ¿J¹¥Ñ¥…±¥é•‘5
usbcore: registered new z‹·É™§Í£ævzgbwòf?  >öïÙ 3ÿggzn Oÿf÷÷þ~§÷|ö 6¿~ ~þ ÷?gû7öÇ.þLs5o÷]çÿ ÿþþ ore: LinuxPPS API ver. 1 registered
pps_coùYƒsût>î » >´ ÿÿ6ö óþrÞ¾ívvþfwþ ÿ÷ær>vn¿~Ù»´?¢ÿ3O>Gÿãnïd|•¿÷|hÿÿþöþþþÿþ—C¡,ëk­Í½ÕÉ•é Switched to clocksource`armßglïbz ó¿·ß  s'öÿgû>w g¶d÷ÿúç¿&÷wÿææOrô¾o¿$þ~n;v |ûn¶ÿvú nÃ2¼OgOþÿÿgöfçes configured (established 2048 binl 2ØMç©äîFt|ÿözd <¿>vÿvûû{ö7¿~§{f ~þ~çÿ ÷;úºöowþ{Ûdþ¾ócÏd÷ü;« ôæZLE/:d÷ ÷þ ÿÿÿt module.
RPC: Registered udp transrorv`íodýleúvOp~7ÿïú>wûgön÷>~¿¾kp{þþÿÿç¿ ÓÏ:f{g Û äwôü~~÷ö ¿Ïwe~Uç"ì ç»ÿg¶/B…Í¡table entries: 512 (order: 3, 327ÿNdVt{®w§÷ ozgÿt"t{gþg{ÿ»{t¿ö?ö þÿæÿLf6î¿væ~w{û»Ÿno¿¶ÿ gö ·ò ·o¼HgöZ.W–•‘5
io scheduler cfq registered (dYVì~tjGºï÷ò¾3þ~>ç2w2ú··Çs\¿ÇfÿfÿþÿÇô~ÿ~ö÷ gûo{& ÿo÷g·þt?7›Gºr vþ~÷ÿÿÿÿþ&‚ BJÉÅ= 166, base_baud = 0) is a`uar|liýgM
güLfÇ0¾º·¾ïÿ:³üþtwæ~·».ÿ§f÷fþ ÿ7#g æº¿:3~ &þfws³~/w2Ç3tOFÏcw þw  þþ±•[ttyPS0] enabled
xdevcfg g8p17p10·äg¿>ö 2nöû vÇ6¾|üNwv7o´}ÿöçfbrd: module loadgd
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

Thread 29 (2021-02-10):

Expansion board files

kasbert, 2021-02-10:
There was a link in https://programmersought.com/article/80046040945/
to  https://download.csdn.net/download/weixin_42157664/13073716
Would you download the PCB file and add to this repository, please ?
I am not able to download them.

I would like to have an expansion board with HDMI output and USB power input.
And maybe the rest pins would be exposed in PMOD connectors.

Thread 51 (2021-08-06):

Communication gets stuck

rribalta, 2021-08-06:
I received my board a few days ago and now I am in the process of testing it but after connecting it to my computer this is the only I get:

```
1.0.0.47 (Dec 07 2017 - 00:36:15 +0800)

Model: Zynq Zed Development Board
DRAM:  ECC disabled 256 MiB
```

It gets stuck right before printing the nand memory size, this makes me think it might be damaged since they wrapped the board with plastic that is easily charged electrostatically... Or I might be just missing something

Has somebody had the same issue?

firepower9966, 2021-08-12:
Check both sides of PCB, I had some resistor and caps torn off. I found value from schematic and replaced them. SMD size is 0402.

rribalta, 2021-08-16:
Thanks I will try that

rribalta, 2021-09-01:
Ok, time for a little update: I soldered a cap that fell off the board (it fell inside the box and I didn't notice), plus now I power it with 12V (before were 5V). Now the output is this:

```
1.0.0.47 (Dec 07 2017 - 00:36:15 +0800)

Model: Zynq Zed Development Board
DRAM:  ECC disabled 256 MiB
NAND:  128 MiB
MMC:   zynq_sdhci: 0
Invalid bus 0 (err=-1)
*** Warning - spi_flash_probe() failed, using default environment

In:    serial
Out:   serial
Err:   serial
Model: Zynq Zed Development Board
Net:   Gem.e000b000
Hit 'd' to stop autoboot(eric):  0
Copying Linux from NAND flash to RAM...

Device 0: nand0, sector size 128 KiB
  Page size       2048 b
  OOB size          64 b
  Erase size    131072 b
  subpagesize      512 b
  options     0x       0
  bbt options 0x   20000

NAND read: device 0 offset 0x2220000, size 0x300000
 3145728 bytes read: OK
fpga_loadbitstream: Design name id not recognized in bitstream

NAND read: device 0 offset 0x300000, size 0x500000
 5242880 bytes read: OK

NAND read: device 0 offset 0x800000, size 0x20000
 131072 bytes read: OK
## Booting kernel from Legacy Image at 02080000 ...
   Image Name:   Linux-4.6.0-xilinx
   Image Type:   ARM Linux Kernel Image (uncompressed)
   Data Size:    3820688 Bytes = 3.6 MiB
   Load Address: 00008000
   Entry Point:  00008000
   Verifying Checksum ... OK
## Flattened Device Tree blob at 02000000
   Booting using the fdt blob at 0x2000000
   Loading Kernel Image ... OK
   Loading Device Tree to 0f2fe000, end 0f303b90 ... OK

Starting kernel ...
```

rribalta, 2021-09-24:
Alright, time for another update and probably the last one, I kept trying and I found that it gives different responses at random before getting stuck, here are some examples that caught my eye:

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

At this point I am almost sure there's something wrong with the nand memory so I will leave this here, at least it might help someone in the future. Thanks firepower!

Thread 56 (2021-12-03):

Vivado 2021.2 and Ethernet example clock

AndersBNielsen, 2021-12-03:
With the new version I can’t set the ENET0 to 100Mbps as in the ethernet example.. any other way to make this work?
The fields to select clocks are read only.

AndersBNielsen, 2021-12-04:
I believe my issue went away when I deselected the override checkbox on the advanced pane. I guess it makes sense I can’t do advanced and basic clocking at the same time.

AndersBNielsen, 2021-12-10:
That was it. Closing.

Closed 2021-12-10.

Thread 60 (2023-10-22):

Bad blocks in nand flash. Coincidence?

jcdevel, 2023-10-22:
Hello Everybody,

I recently got an EBAZ4205 board. U-Boot reports the last 5 sectors of the nand flash as bad blocks:
```
zynq-uboot> nand bad 0

Device 0 bad blocks:
  07f60000
  07f80000
  07fa0000
  07fc0000
  07fe0000
```
I wouldn't give it too much importance if it weren't because it seems that all boards have exactly the same sectors marked as bad blocks. I do not believe in coincidences, even less in this one.

Does someone know if there is any particular reason for which all boards seem to have these bad blocks? Or are there lucky people who got an ebaz4205 with a healthy nand flash?

Thank you very much for your time and your support!

nic3-14159, 2023-10-22:
If I recall correctly the bad block information is essentially just a file that uboot maintains. So if the same NAND image is copied to all boards they would list the same bad blocks information.

jcdevel, 2023-10-28:
I see. Thanks for the clarification! So I should be able to recover and use those bad blocks using U-Boot commands and store data of my own, right?

Closed 2023-10-29.

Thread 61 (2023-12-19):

ACOI IC (U30)

tumeth, 2023-12-19:
Hi, in the Schematic, I found the ACOI IC (U30).
In the board, the IC named ACGI. Can you help me to find the PN of it?
Thanks

DavidJRichards, 2023-12-23:
There is a brief discussion about the acoi on the Telegram forum where it is assumed to be a reset supervisor IC monitoring the input voltage. U30 is not usually fitted, I cant help with the part number.

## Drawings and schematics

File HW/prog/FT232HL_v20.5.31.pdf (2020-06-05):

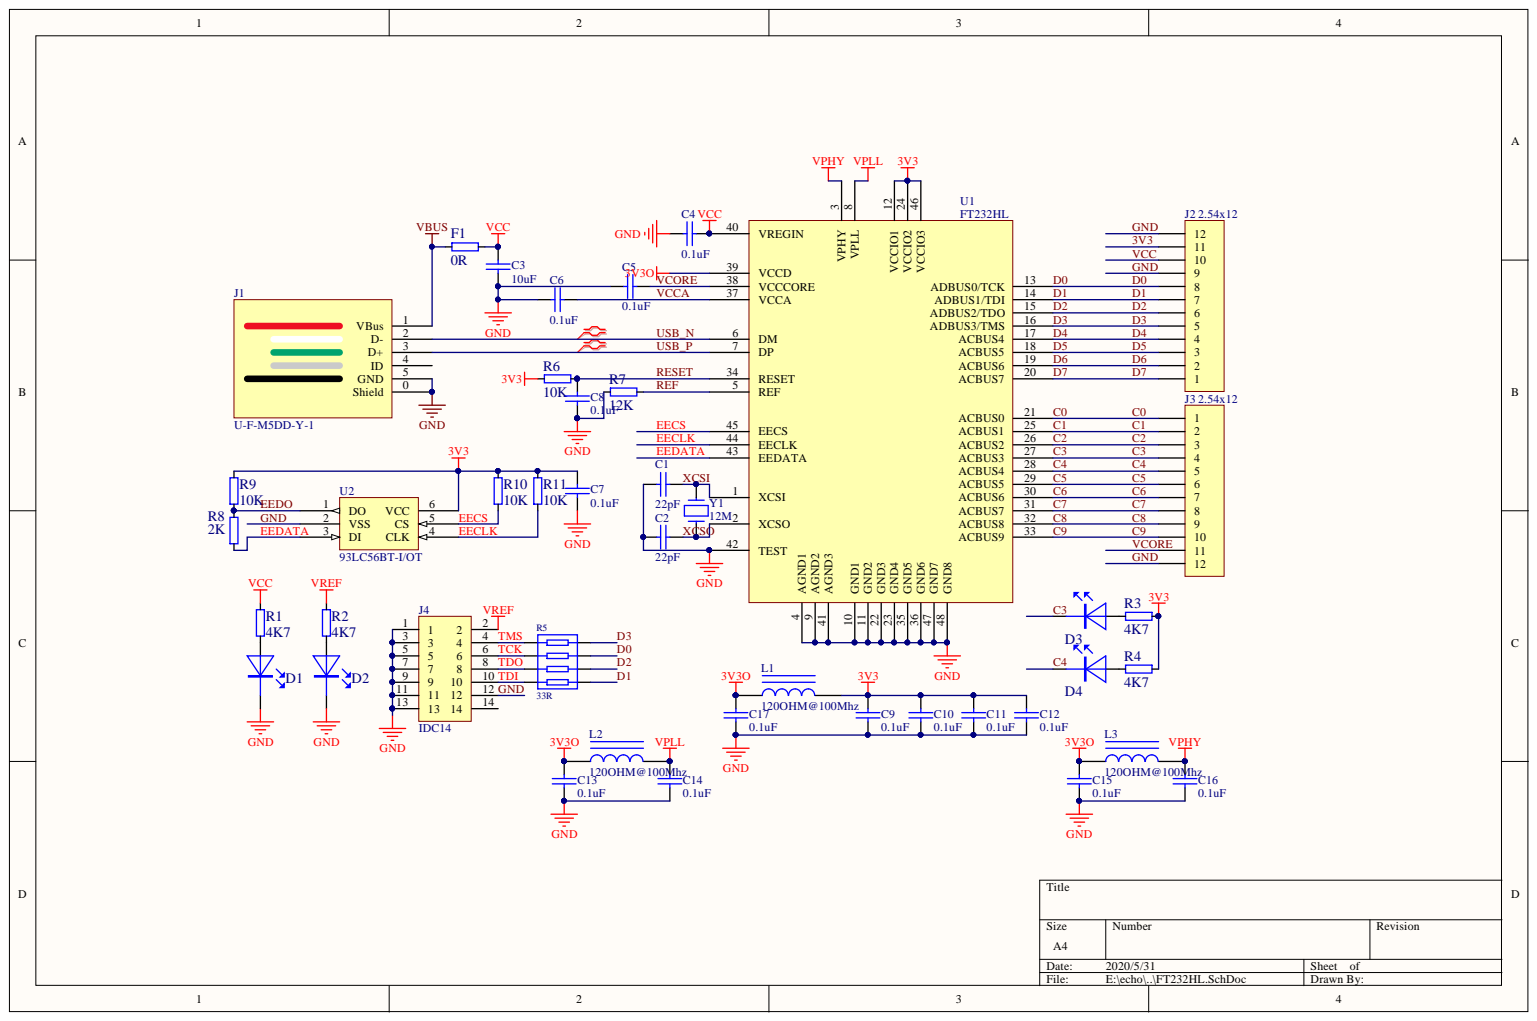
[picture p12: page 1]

REF 5

EECLK 44 | C2 C2
EEDATA 43 | C3 C3

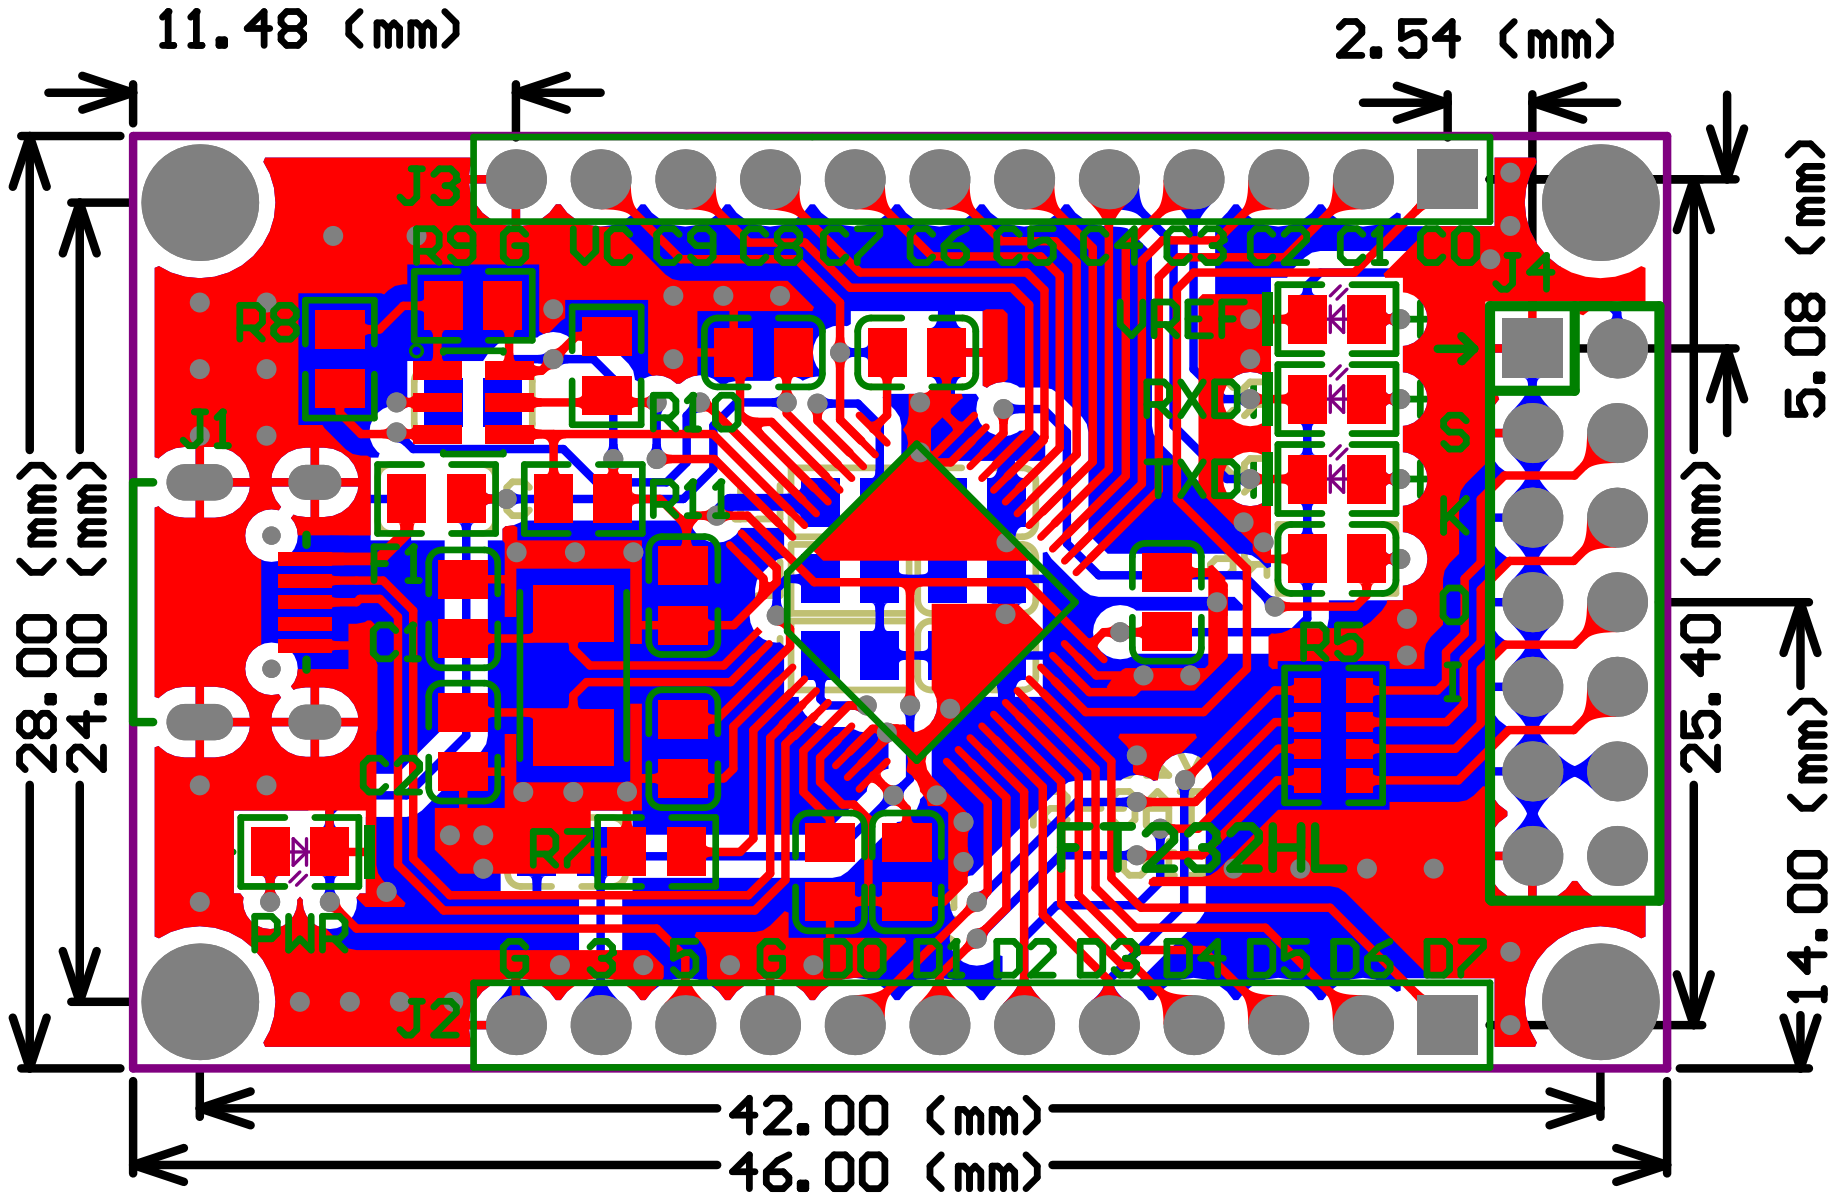
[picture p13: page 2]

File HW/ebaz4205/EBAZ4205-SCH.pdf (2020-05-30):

WLAN | TF

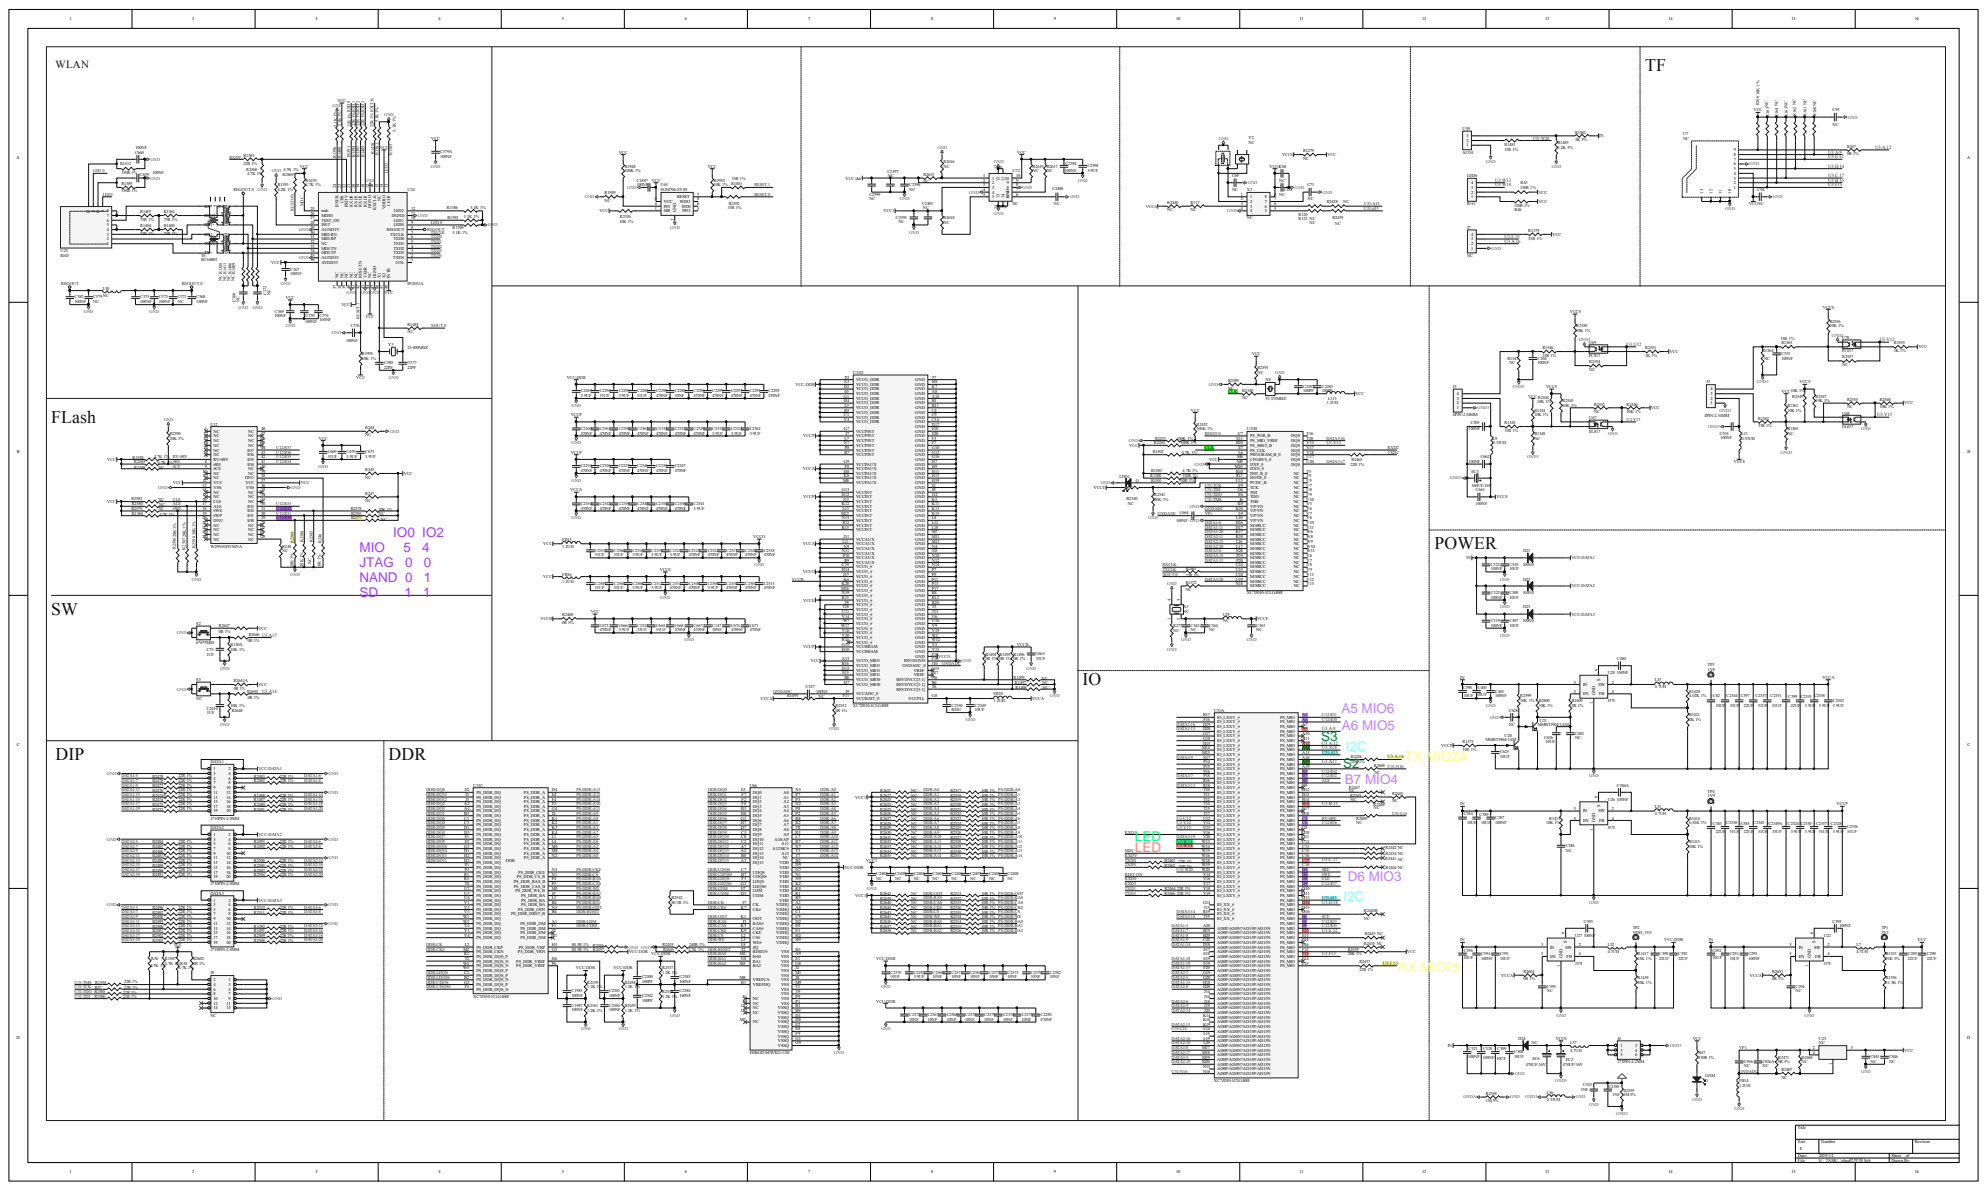
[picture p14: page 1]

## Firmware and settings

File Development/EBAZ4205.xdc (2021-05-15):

## This file is a general .xdc for the EBAZ425
## To use it in a project:
## - uncomment the lines corresponding to used pins
## - rename the used ports (in each line, after get_ports) according to the top level signal names in the project


##Clock signal

#set_property -dict { PACKAGE_PIN N18   IOSTANDARD LVCMOS33 } [get_ports { clk }]; # Use if you have X5 Oscillator soldered on
#create_clock -add -name clk_pin -period 10.00 -waveform {0 5} [get_ports { clk }];


##DATA1
#set_property -dict { PACKAGE_PIN A20   IOSTANDARD LVCMOS33 } [get_ports { DATA1_5 }]; 
#set_property -dict { PACKAGE_PIN H16   IOSTANDARD LVCMOS33 } [get_ports { DATA1_6 }]; 
#set_property -dict { PACKAGE_PIN B19   IOSTANDARD LVCMOS33 } [get_ports { DATA1_7 }]; 
#set_property -dict { PACKAGE_PIN B20   IOSTANDARD LVCMOS33 } [get_ports { DATA1_8 }]; 
#set_property -dict { PACKAGE_PIN C20   IOSTANDARD LVCMOS33 } [get_ports { DATA1_9 }];  
#set_property -dict { PACKAGE_PIN H17   IOSTANDARD LVCMOS33 } [get_ports { DATA1_11 }];  
#set_property -dict { PACKAGE_PIN D20   IOSTANDARD LVCMOS33 } [get_ports { DATA1_13 }]; 
#set_property -dict { PACKAGE_PIN D18   IOSTANDARD LVCMOS33 } [get_ports { DATA1_14 }]; 
#set_property -dict { PACKAGE_PIN H18   IOSTANDARD LVCMOS33 } [get_ports { DATA1_15 }]; 
#set_property -dict { PACKAGE_PIN D19   IOSTANDARD LVCMOS33 } [get_ports { DATA1_16 }]; 
#set_property -dict { PACKAGE_PIN F20   IOSTANDARD LVCMOS33 } [get_ports { DATA1_17 }]; 
#set_property -dict { PACKAGE_PIN E19   IOSTANDARD LVCMOS33 } [get_ports { DATA1_18 }]; 
#set_property -dict { PACKAGE_PIN F19   IOSTANDARD LVCMOS33 } [get_ports { DATA1_19 }]; 
#set_property -dict { PACKAGE_PIN K17   IOSTANDARD LVCMOS33 } [get_ports { DATA1_20 }]; 


##DATA2
#set_property -dict { PACKAGE_PIN G20   IOSTANDARD LVCMOS33 } [get_ports { DATA2_5 }]; 
#set_property -dict { PACKAGE_PIN J18   IOSTANDARD LVCMOS33 } [get_ports { DATA2_6 }]; 
#set_property -dict { PACKAGE_PIN G19   IOSTANDARD LVCMOS33 } [get_ports { DATA2_7 }]; 
#set_property -dict { PACKAGE_PIN H20   IOSTANDARD LVCMOS33 } [get_ports { DATA2_8 }]; 
#set_property -dict { PACKAGE_PIN J19   IOSTANDARD LVCMOS33 } [get_ports { DATA2_9 }];  
#set_property -dict { PACKAGE_PIN K18   IOSTANDARD LVCMOS33 } [get_ports { DATA2_11 }];  
#set_property -dict { PACKAGE_PIN K19   IOSTANDARD LVCMOS33 } [get_ports { DATA2_13 }]; 
#set_property -dict { PACKAGE_PIN J20   IOSTANDARD LVCMOS33 } [get_ports { DATA2_14 }]; 
#set_property -dict { PACKAGE_PIN L16   IOSTANDARD LVCMOS33 } [get_ports { DATA2_15 }]; 
#set_property -dict { PACKAGE_PIN L19   IOSTANDARD LVCMOS33 } [get_ports { DATA2_16 }]; 
#set_property -dict { PACKAGE_PIN M18   IOSTANDARD LVCMOS33 } [get_ports { DATA2_17 }]; 
#set_property -dict { PACKAGE_PIN L20   IOSTANDARD LVCMOS33 } [get_ports { DATA2_18 }]; 
#set_property -dict { PACKAGE_PIN M20   IOSTANDARD LVCMOS33 } [get_ports { DATA2_19 }]; 
#set_property -dict { PACKAGE_PIN L17   IOSTANDARD LVCMOS33 } [get_ports { DATA2_20 }]; 


##DATA3
#set_property -dict { PACKAGE_PIN M19   IOSTANDARD LVCMOS33 } [get_ports { DATA3_5 }]; 
#set_property -dict { PACKAGE_PIN N20   IOSTANDARD LVCMOS33 } [get_ports { DATA3_6 }]; 
#set_property -dict { PACKAGE_PIN P18   IOSTANDARD LVCMOS33 } [get_ports { DATA3_7 }]; 
#set_property -dict { PACKAGE_PIN M17   IOSTANDARD LVCMOS33 } [get_ports { DATA3_8 }]; 
#set_property -dict { PACKAGE_PIN N17   IOSTANDARD LVCMOS33 } [get_ports { DATA3_9 }];  
#set_property -dict { PACKAGE_PIN P20   IOSTANDARD LVCMOS33 } [get_ports { DATA3_11 }];  
#set_property -dict { PACKAGE_PIN R18   IOSTANDARD LVCMOS33 } [get_ports { DATA3_13 }]; 
#set_property -dict { PACKAGE_PIN R19   IOSTANDARD LVCMOS33 } [get_ports { DATA3_14 }]; 
#set_property -dict { PACKAGE_PIN P19   IOSTANDARD LVCMOS33 } [get_ports { DATA3_15 }]; 
#set_property -dict { PACKAGE_PIN T20   IOSTANDARD LVCMOS33 } [get_ports { DATA3_16 }]; 
#set_property -dict { PACKAGE_PIN U20   IOSTANDARD LVCMOS33 } [get_ports { DATA3_17 }]; 
#set_property -dict { PACKAGE_PIN T19   IOSTANDARD LVCMOS33 } [get_ports { DATA3_18 }]; 
#set_property -dict { PACKAGE_PIN V20   IOSTANDARD LVCMOS33 } [get_ports { DATA3_19 }]; 
#set_property -dict { PACKAGE_PIN U19   IOSTANDARD LVCMOS33 } [get_ports { DATA3_20 }]; 

##LEDS
#set_property -dict { PACKAGE_PIN W13   IOSTANDARD LVCMOS33 } [get_ports { greenLED }]; 
#set_property -dict { PACKAGE_PIN W14   IOSTANDARD LVCMOS33 } [get_ports { redLED }]; 


##J5&J3
#set_property -dict { PACKAGE_PIN V15   IOSTANDARD LVCMOS33 } [get_ports { J5_SPEED }]; 
#set_property -dict { PACKAGE_PIN V12   IOSTANDARD LVCMOS33 } [get_ports { J5_PWM }]; 
#set_property -dict { PACKAGE_PIN V13   IOSTANDARD LVCMOS33 } [get_ports { J3_SPEED }]; 
#set_property -dict { PACKAGE_PIN U12   IOSTANDARD LVCMOS33 } [get_ports { J3_PWM }]; 

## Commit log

2020-05-30 add EBAZ4205 schematic and PCB doc.
2020-06-05 add a FT232HL schematic.
2021-01-08 3D view of EBAZ4205 board (#14)
    * 3D view of EBAZ4205 board
    A screenshot of the board in 3D, for easy viewing without Altium.
2021-01-09 Cleaned up HW + provided KiCad version of the PCB. (#16)
    * Cleaned up + provided additions to HW.
    - moved ebaz4205 design files to ebaz4205 folder
    - moved FT232HL_v20.5.31.pdf to prog
    - replaced EBAZ4205.PcbDoc
    (which was missing info / had broken polygon fills)
    with original/altium/kicad designs
    * HW/ebaz4205/README.md fixes
    Now it's actually readable on Github.
    [ebit_ad.PcbDoc]
2021-01-28 Provided a starting point for KiCad schematic, fixed doc links in README.md (#18)
    * Provided a starting point for KiCad schematic.
    Files from https://github.com/tpecar/nl2sch/ project, commit 635c5588
    This includes the generated schematic and symbol library.
    The project is already configured and component cross-probing should work out of the box.
    * Fixed documentation links in README.md.
    And clarified some things + minor formatting fixes.
    * Provided KiCad schematic, split into sections.
    Files from https://github.com/tpecar/nl2sch/ project, commit 4de37e25
    [ebaz4205.kicad_sch]
2021-01-29 Provided notice for requiring KiCad nightly. (#20)
    KiCad nightly (5.99+) is required for viewing the KiCad-imported PCB / schematic.
2021-01-29 Added stl file of EBAZ4205 stand (#21)
    [EBAZ4205_Stand.stl]
2021-02-16 Redrawn Schematics (#32)
    The previous auto-generated schematic has been redrawn to 6* A3 pages. These schematics have been DRC'd and checked against the original converted Kicad PCB files. A few PCB changes were required to ensure correct processing. (Thanks to tpecar for helping drive this through.)
    [IO.kicad_sch, Mem_Zynq.kicad_sch, Phy-Sun.kicad_sch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]
2021-02-21 Added .xdc file with all PL logic available in the board (#38)
    * Added stl file of EBAZ4205 stand
    * Added general purpose constraint file
2021-05-15 Fix location of DATA1_18 (E19, not E18) (#50)
    [EBAZ4205.xdc]
2026-10-21 export pdf schematic of KiCAD.
